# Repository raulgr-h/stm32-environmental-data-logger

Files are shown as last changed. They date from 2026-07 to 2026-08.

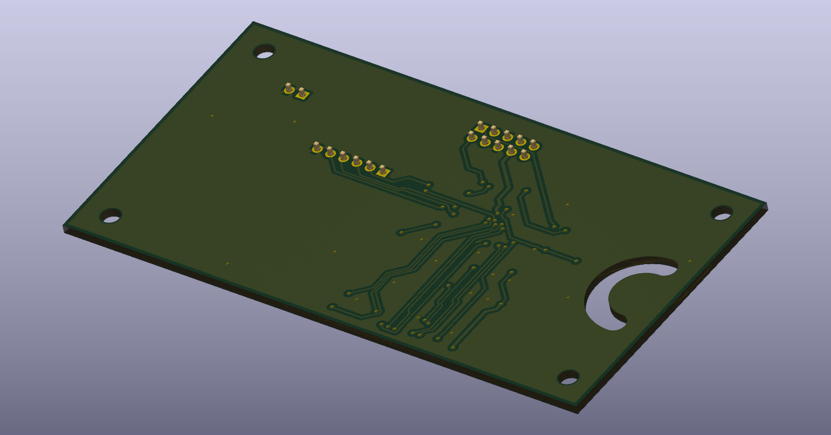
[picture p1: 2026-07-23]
hardware/renders/3dview_bottom.png

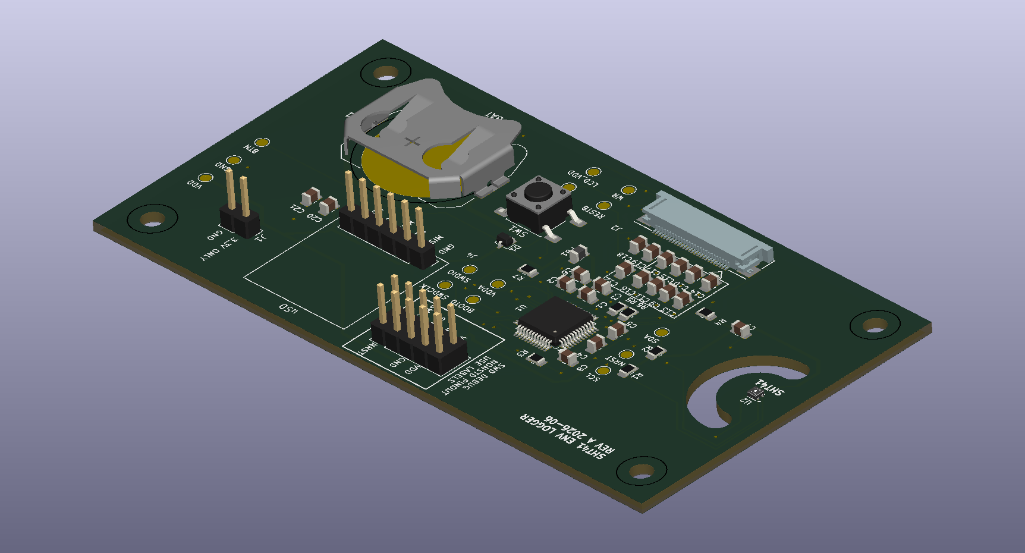
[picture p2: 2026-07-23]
hardware/renders/3dview_opposite.png

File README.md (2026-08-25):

# STM32L431 Environmental Data Logger

A custom embedded environmental data logger built around the STM32L431 microcontroller.

The project began as a hand-assembled Rev A PCB integrating an SHT41 environmental sensor, SPI microSD storage, RTC timestamping, and STM32 firmware. Rev A was brought through board bring-up, firmware integration, protocol debugging, long-duration logging, and electrical characterization.

Development has now progressed to a Rev B redesign informed by measured Rev A behavior, with emphasis on lower-power operation, improved nonvolatile storage, BLE connectivity, and systematic hardware validation.

---

## Project Status

### Rev A — Functional and Characterized

The core Rev A environmental logging path has been successfully brought up and verified.

Verified functionality includes:

- STM32L431 firmware execution and SWD debugging
- SHT41 temperature and relative-humidity measurements over I2C
- SPI-mode microSD initialization and sector access
- FatFs mount, file open, append, write, sync, and close operations
- STM32 RTC initialization and timestamp generation
- RTC-timestamped, PC-readable CSV logging
- Nonblocking push-button-controlled logging
- Multi-hour logging operation
- Zero observed SPI transfer failures during verified long-duration runs
- Logic-analyzer verification of I2C and SPI transactions
- Oscilloscope and Analog Discovery 2 electrical measurements
- Board-level current and supply-transient characterization
- Automated CR2032 pulse-load characterization

Rev A is retained as the verified hardware baseline for continued development.

### Rev B — In Development

Rev B is being developed from Rev A test results and system-level lessons.

Current design changes include:

- Replacement of microSD storage with an ST M95P16 SPI Page EEPROM
- Addition of a 32.768 kHz LSE crystal for RTC and low-power operation
- Addition of a CYBLE-416045-02 BLE module
- STM32-to-BLE UART communication
- Dedicated BLE programming/debug access
- Revised low-power architecture
- Updated user controls and interfaces
- PCB changes informed by measured battery and transient-load behavior

Rev B schematic development is maintained separately from the archived Rev A hardware baseline.

---

## System Architecture

### Rev A

- **Microcontroller:** STM32L431CBT6
- **Environmental Sensor:** Sensirion SHT41
- **Sensor Interface:** I2C
- **Storage:** microSD over SPI
- **Filesystem:** FatFs
- **Timekeeping:** STM32 RTC
- **Firmware:** Embedded C using STM32 HAL
- **PCB Design:** KiCad
- **Development Environment:** STM32CubeIDE
- **Test Equipment:** Digilent Analog Discovery 2, DMM, oscilloscope, and logic analyzer

### Rev B

- **Microcontroller:** STM32L431CBT6
- **Environmental Sensor:** Sensirion SHT41
- **Nonvolatile Storage:** ST M95P16 SPI Page EEPROM
- **Wireless Interface:** Infineon CYBLE-416045-02 BLE module
- **BLE Host Interface:** UART
- **RTC Reference:** External 32.768 kHz LSE crystal
- **PCB Design:** KiCad

---

## Firmware Development

Rev A firmware includes:

- STM32 HAL peripheral configuration
- SHT41 command and measurement handling
- Low-level SPI SD communication
- SD initialization using CMD0, CMD8, CMD55, ACMD41, and CMD58
- Sector-level SD access
- FatFs disk-I/O integration
- RTC initialization and timestamp generation
- Backup-register handling for RTC state
- Timestamped CSV creation and append operations
- Nonblocking push-button debounce and logging-state control
- Reusable sensor-to-storage logging routines
- SPI error instrumentation
- Time-based communication timeout handling

Rev B firmware development will extend the platform with:

- SPI EEPROM storage
- Lower-power operating modes
- BLE coprocessor communication
- Wireless environmental-data transfer

---

## Automated Test and Characterization

A Python-based automated test environment was developed using the Digilent WaveForms SDK and Analog Discovery 2.

The test fixture uses transistor-switched resistive loads and synchronized analog acquisition to characterize battery and PCB supply behavior under controlled transient loads.

Capabilities include:

- Automated selection of multiple load conditions
- Configurable pulse durations
- Repeated transient tests
- Analog acquisition at up to 100 kS/s
- Synchronized battery and shunt-voltage measurement
- Current calculation from calibrated shunt measurements
- Pre-pulse baseline measurement
- Minimum battery-voltage detection
- PCB supply-voltage analysis
- Voltage-droop calculation
- Recovery-voltage analysis
- Pulse-duration validation
- Acquisition-integrity monitoring
- Per-test raw waveform CSV logging
- Reduced summary-metric generation
- Automatic load removal after each test
- Configurable 2.40 V low-voltage safety cutoff

The characterization framework progressed from basic manual load switching and averaged measurements to automated transient waveform capture, focused pulse testing, and repeatability testing.

These measurements are being used to inform Rev B power, storage, and low-power design decisions.

---

## Electrical Characterization

Rev A current and supply behavior were measured during normal environmental logging and controlled load testing.

Verified observations include:

- Approximately **2.1 mA average board current** during 5 s interval logging
- Sampled transient current peaks of approximately **25 mA** at 500 kHz during sensor and microSD activity
- Measurable VDD droop correlated with current transients
- Successful CSV writes despite the observed transient supply behavior
- Repeatable CR2032 transient-load measurements using automated acquisition
- Preservation of raw waveforms for later engineering analysis

The automated test setup enables battery behavior to be compared across different loads, pulse durations, and repeated test runs rather than relying only on static current measurements.

---

## Verification

The system has been verified using:

- STM32CubeIDE debugging
- Runtime firmware instrumentation
- DMM resistance, continuity, and voltage measurements
- Oscilloscope measurements
- Digilent Analog Discovery 2 analog acquisition
- Logic-analyzer protocol captures
- Long-duration CSV logging
- Automated transient-load testing
- Repeatability testing
- Git revision and diff analysis during debugging

Key verified results include:

- `FR_OK` for successful FatFs mount, open, write, sync, and close operations
- `HAL_OK` during verified SHT41 communication
- Successful SPI SD initialization
- Successful CMD17 read transactions
- Verified SHT41 I2C command and response transactions
- RTC-timestamped, PC-readable CSV files
- Button input correlated with subsequent sensor sampling and storage activity
- Multi-hour logging with zero observed SPI transfer failures during verified runs

---

## Debugging Case Studies

### SD Hardware Fault

During Rev A bring-up, the SD card ground connection measured approximately 5 MΩ because of a poor solder joint.

The fault was isolated using resistance and continuity measurements and corrected by reflowing the affected connection.

This restored a valid low-resistance ground connection and allowed SD communication debugging to continue.

### FatFs Write Failure

A later firmware issue caused the first FatFs write operation to appear to hang.

Investigation showed that the SPI peripheral remained at the low initialization clock after SD startup while the disk driver used iteration-count-based ready timeouts.

The corrective actions included:

- Increasing the SPI clock after SD initialization
- Replacing iteration-count polling with `HAL_GetTick()`-based timeouts
- Adding SPI transfer-failure instrumentation

After correction, file open, write, sync, and close operations completed successfully.

### CubeMX Regeneration Regression

A later STM32CubeMX regeneration overwrote the customized `user_diskio.c` implementation, causing FatFs operations to return `FR_NOT_READY`.

The regression was isolated using:

- Runtime return-code instrumentation
- Git revision comparison
- Source diff analysis

Restoring the previously verified disk-I/O implementation recovered normal SD and FatFs operation.

This demonstrated the use of source control not only for version management, but also as a firmware-debugging and regression-analysis tool.

---

## Hardware Revision Strategy

Rev A is retained as a frozen hardware baseline rather than being modified in place.

Rev B development is maintained separately so design changes can be traced back to measured Rev A behavior and validation results.

```text
hardware/kicad/
├── rev-a/          Verified Rev A hardware baseline
├── rev-b/          Rev B hardware development
├── symbols/        Project-specific schematic symbols
├── footprints/     Project-specific PCB footprints
└── 3dmodels/       Component mechanical models
```

The `rev-a-hardware` Git tag preserves the Rev A hardware milestone.

---

## Repository Structure

```text
hardware/
└── kicad/
    ├── rev-a/
    ├── rev-b/
    ├── symbols/
    ├── footprints/
    └── 3dmodels/

firmware/
└── STM32CubeIDE project and embedded firmware

test/
├── scripts/
│   └── ate/
├── raw-data/
├── processed-data/
└── results/

docs/
├── design/
├── bringup/
└── images/

releases/
└── Release and milestone documentation
```

### Automated Test Scripts

The primary automated characterization scripts are maintained under:

```text
test/scripts/ate/
```

They cover:

- Full pulse-load characterization
- Focused pulse testing
- Repeatability testing
- Rev A system-level load testing

Raw acquisition data and processed engineering results are maintained separately to preserve traceability between measurement evidence and reduced summary metrics.

---

## Engineering Scope

This project serves as an end-to-end embedded hardware development platform covering:

- PCB schematic and layout development
- Hardware revision control
- Hand assembly and board bring-up
- STM32 embedded firmware development
- I2C and SPI protocol implementation
- Sensor integration
- Embedded filesystem integration
- RTC and timestamped data acquisition
- Hardware/firmware debugging
- Oscilloscope and logic-analyzer validation
- Automated hardware testing
- Python test automation
- Battery and transient-load characterization
- Root-cause failure analysis
- Design-for-low-power development
- BLE subsystem development
- Git/GitHub engineering workflow

---

## Next Development Steps

Current development is focused on Rev B, including:

- Completing Rev B schematic design review
- PCB layout and design-rule verification
- M95P16 storage-driver development
- BLE subsystem prototyping and UART communication
- Low-power firmware development
- Rev B assembly and bring-up
- Power-consumption comparison between Rev A and Rev B
- Environmental logging validation using the revised architecture

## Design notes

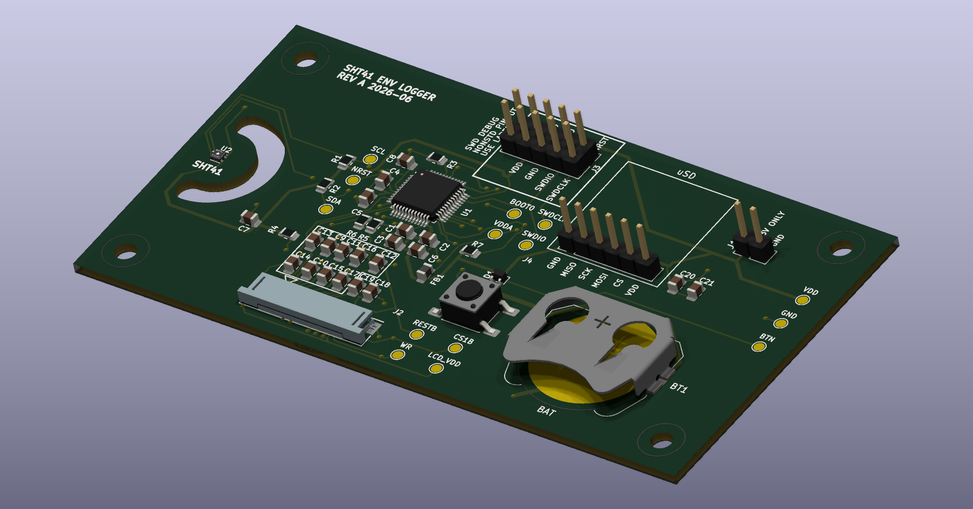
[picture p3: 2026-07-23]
hardware/renders/3dview_top.png

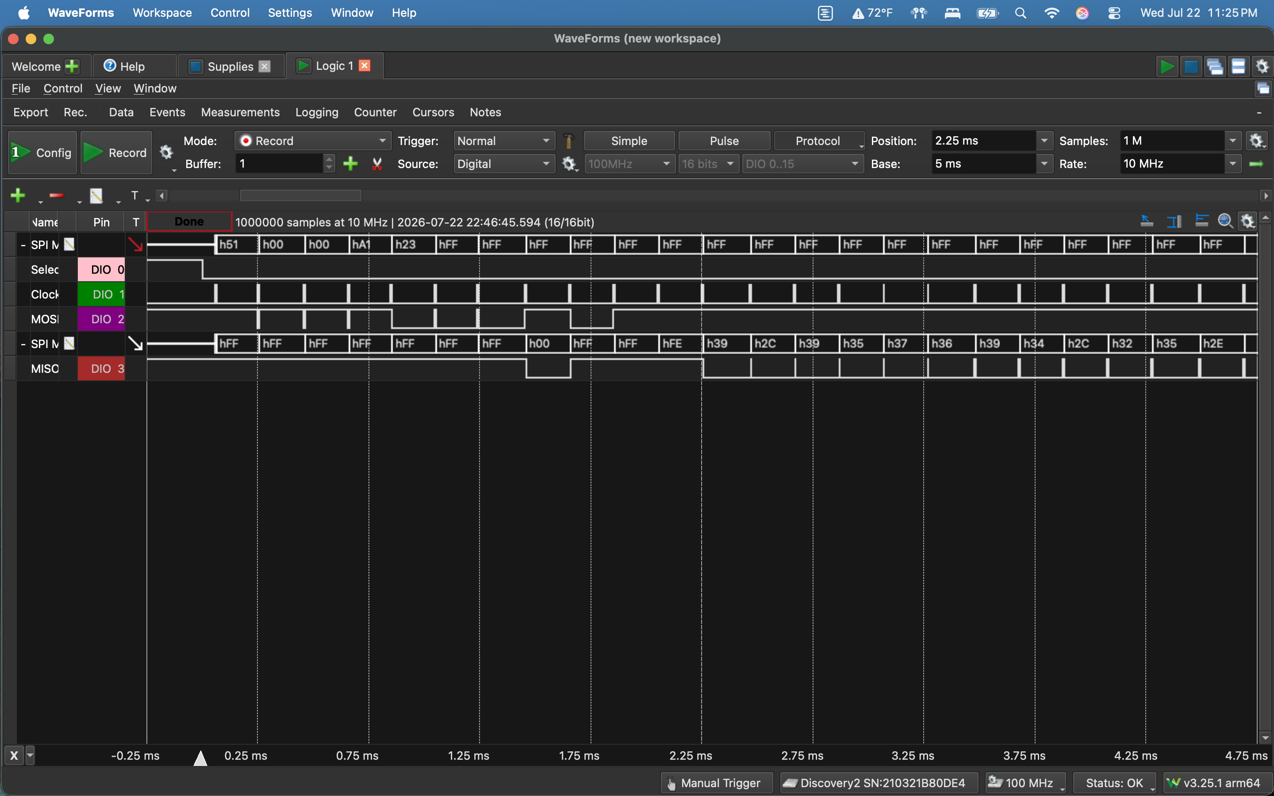
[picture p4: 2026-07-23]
docs/images/Waveforms/SD SPI Transaction - Logic.png

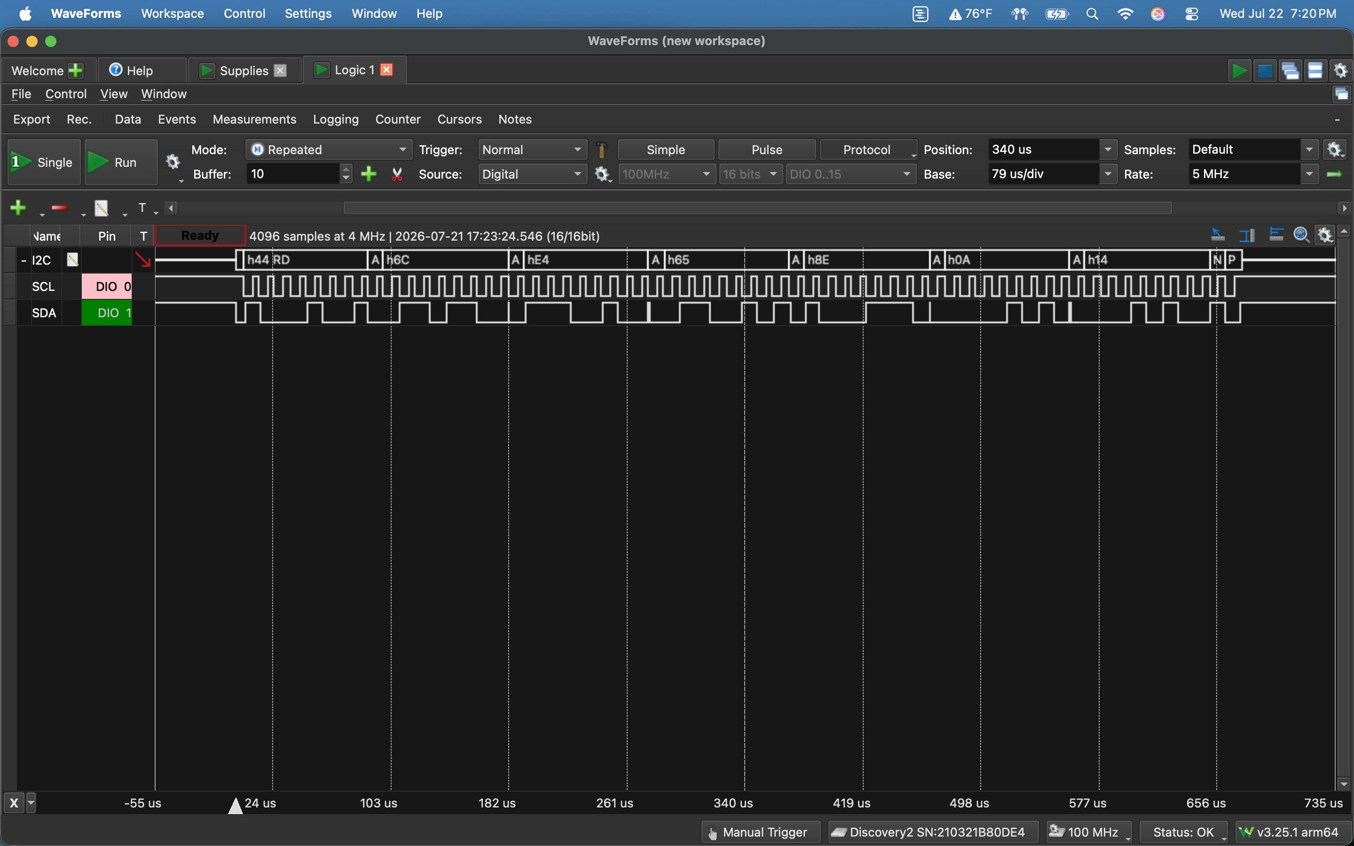
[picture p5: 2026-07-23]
docs/images/Waveforms/I2C transaction for SHT41 - Logic.png

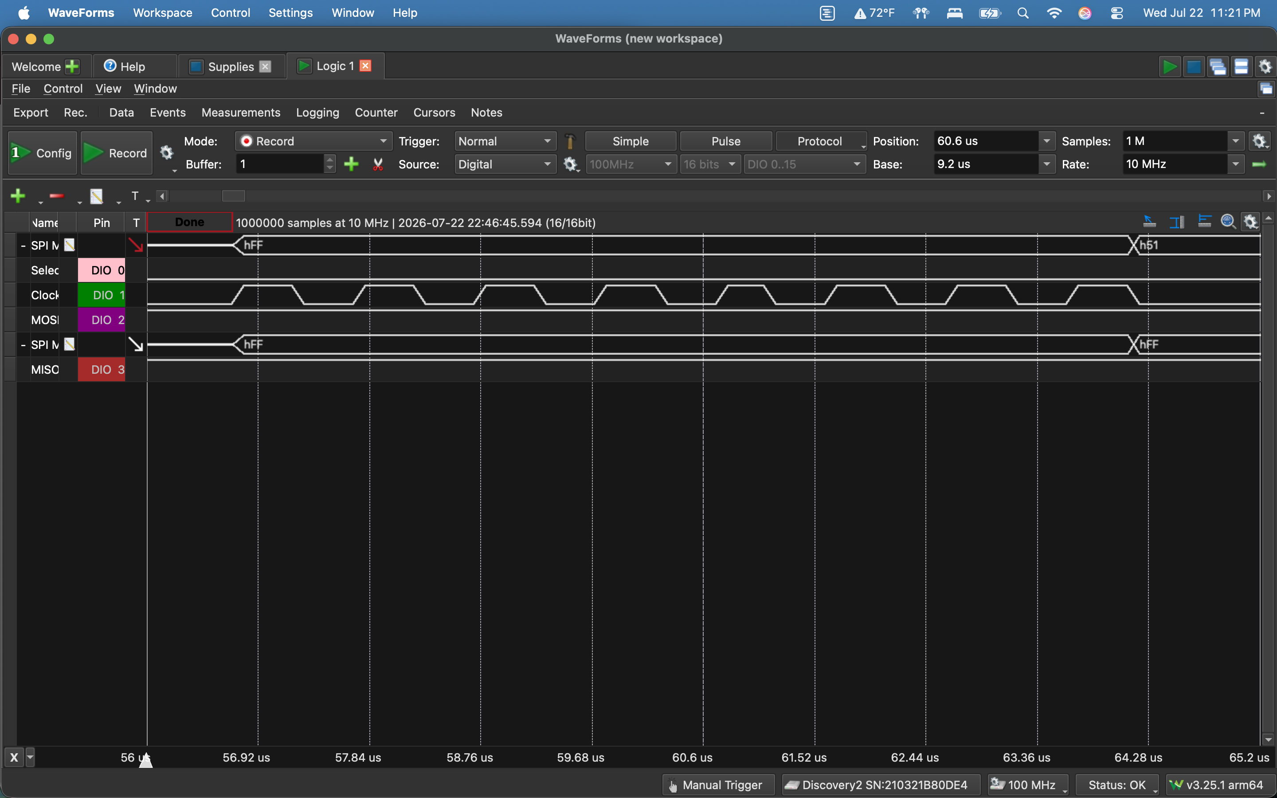
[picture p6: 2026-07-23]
docs/images/Waveforms/SD SPI Transaction (Zoomed) - Logic.png

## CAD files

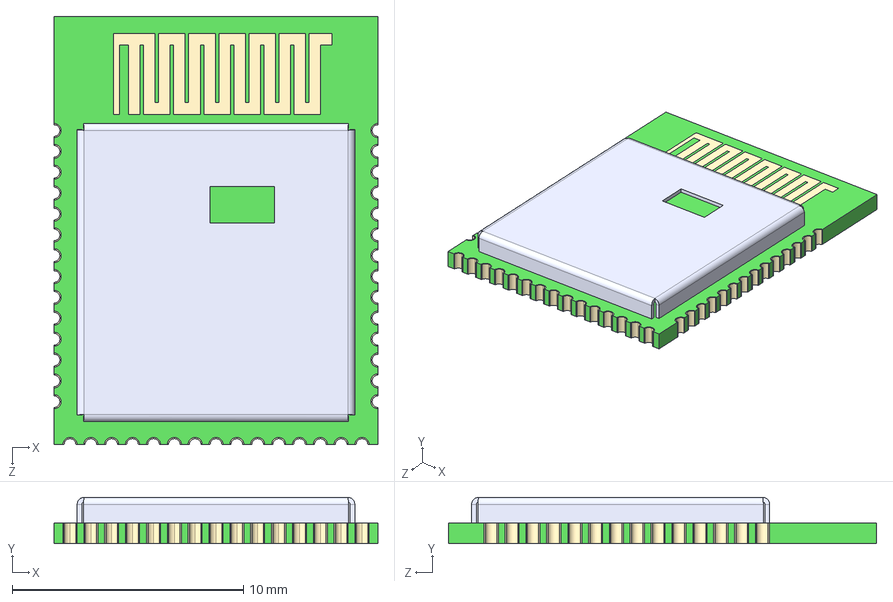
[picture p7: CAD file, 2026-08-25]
hardware/kicad/3dmodels/CYBLE-416045-02.step
14.0 x 2.00 x 18.5 mm

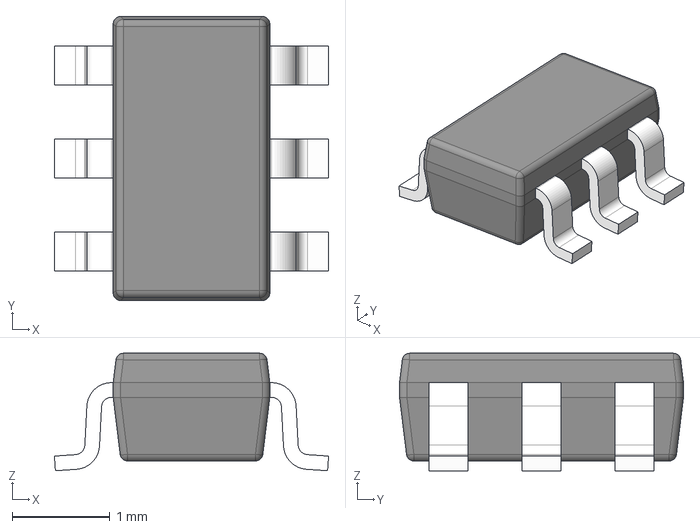
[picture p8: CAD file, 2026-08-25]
hardware/kicad/3dmodels/DBV0006A.stp
2.80 x 2.90 x 1.20 mm
BODY-SOT
LEAD-SOT x 6

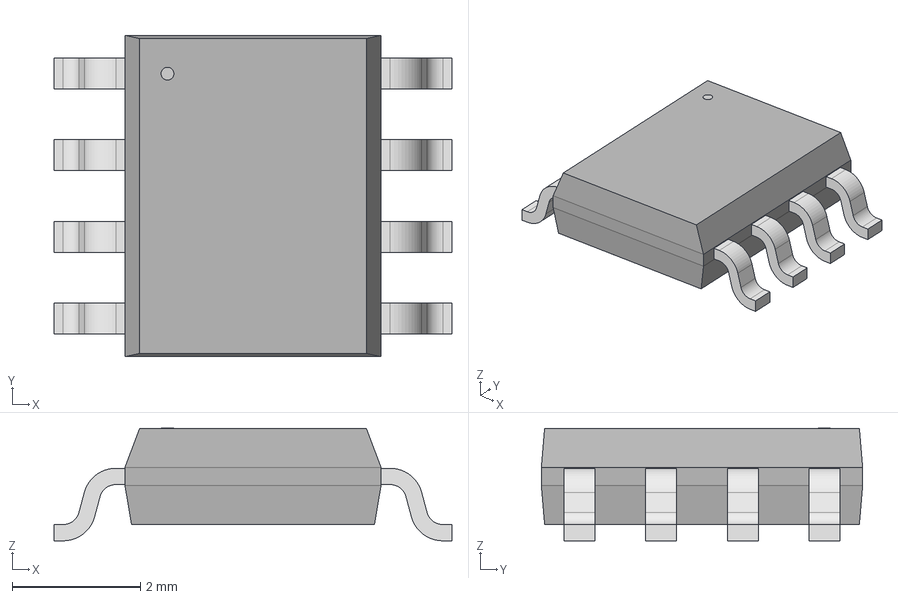
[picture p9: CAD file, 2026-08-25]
hardware/kicad/3dmodels/SO8N_4x5_FTL1p27_STM.step
6.20 x 5.00 x 1.75 mm

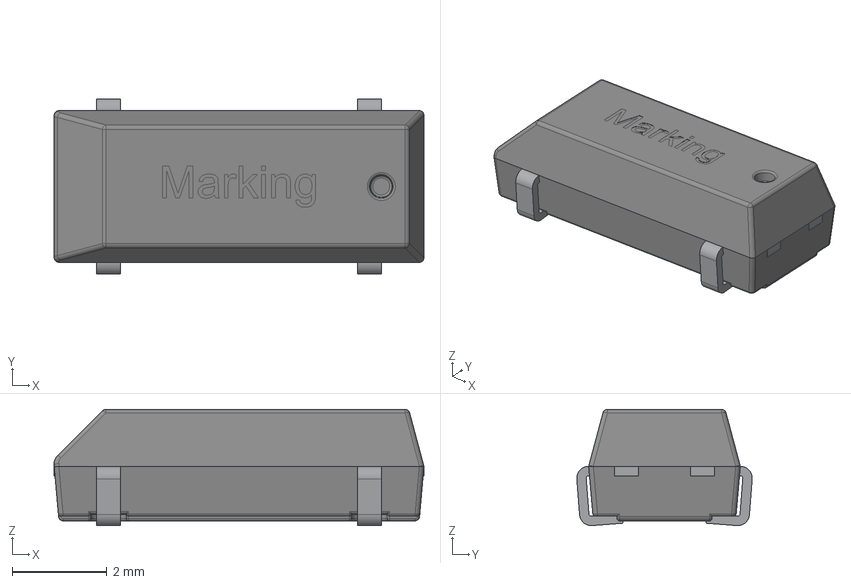
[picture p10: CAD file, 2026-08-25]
hardware/kicad/3dmodels/LFXTAL016178.step
7.80 x 3.70 x 2.45 mm
Base
TopCover
Pin

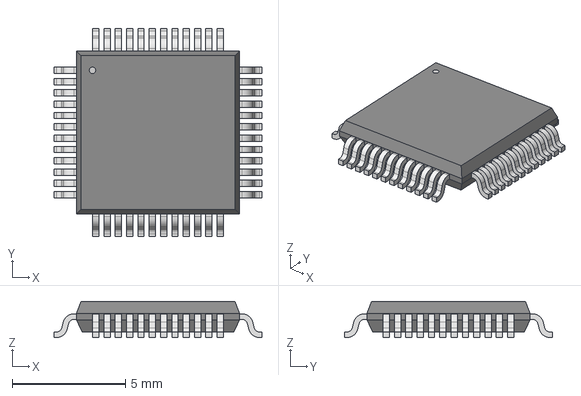
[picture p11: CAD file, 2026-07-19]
hardware/kicad/3dmodels/LQFP-48.step
9.19 x 9.19 x 1.60 mm

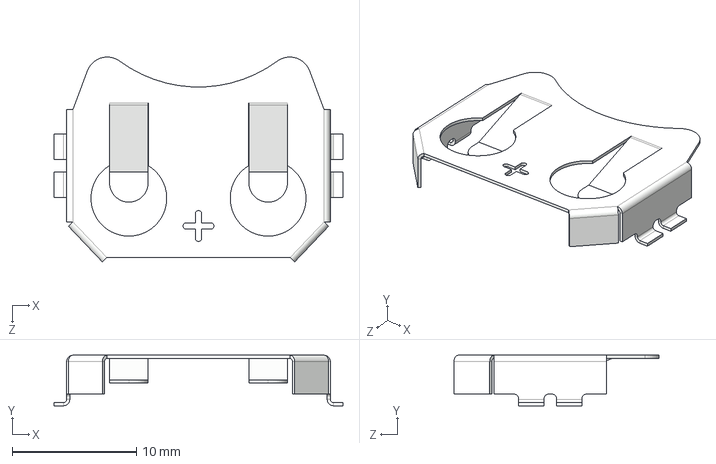
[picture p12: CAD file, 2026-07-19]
hardware/kicad/3dmodels/3034.step
23.2 x 4.06 x 16.5 mm

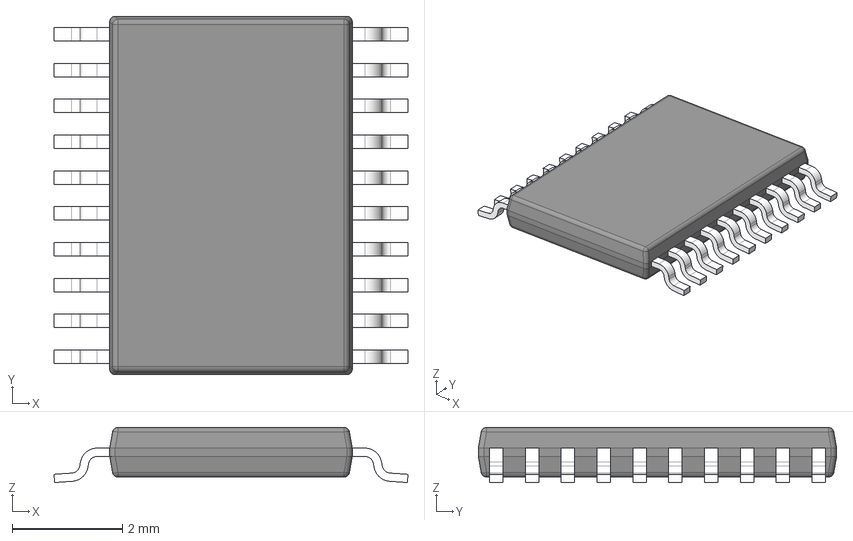
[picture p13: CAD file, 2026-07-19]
hardware/kicad/3dmodels/PWP0020A.stp
6.42 x 6.50 x 1.00 mm
BODY-SO
LEAD-SO x 20
THERMALPAD-SO
PIN1-ID

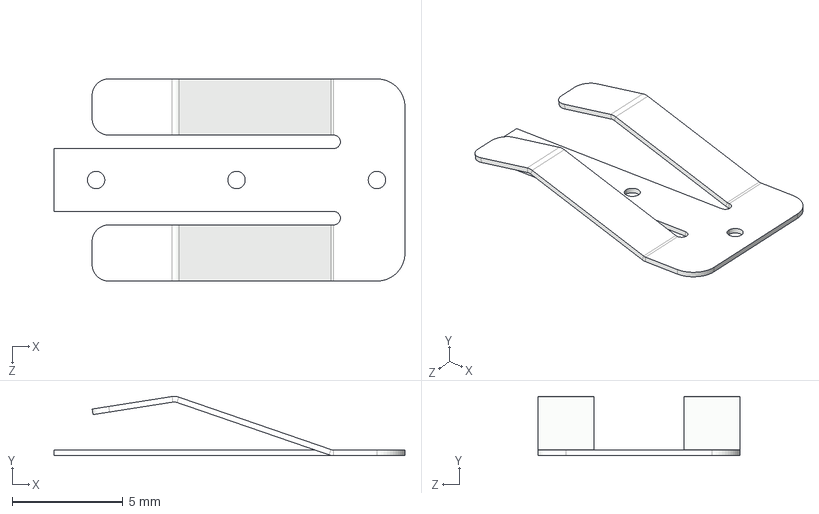
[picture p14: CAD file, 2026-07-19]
hardware/kicad/3dmodels/2993.STEP
15.9 x 2.68 x 9.14 mm

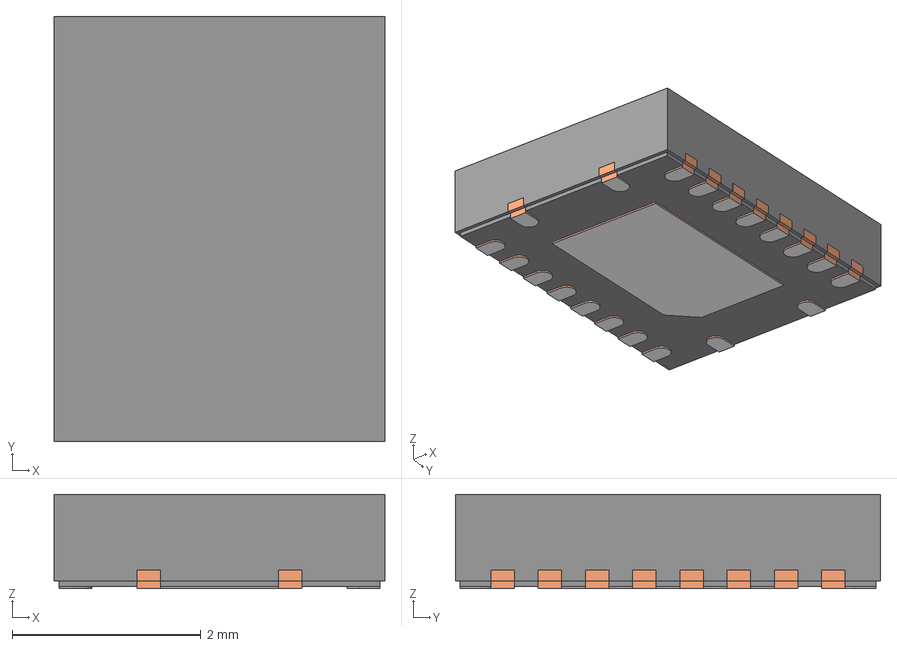
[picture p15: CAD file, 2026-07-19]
hardware/kicad/3dmodels/RGY0020B.stp
3.50 x 4.50 x 1.00 mm
BODY-QFN_AF0
FRAME-RGY0020B_AF0
PIN1-ID

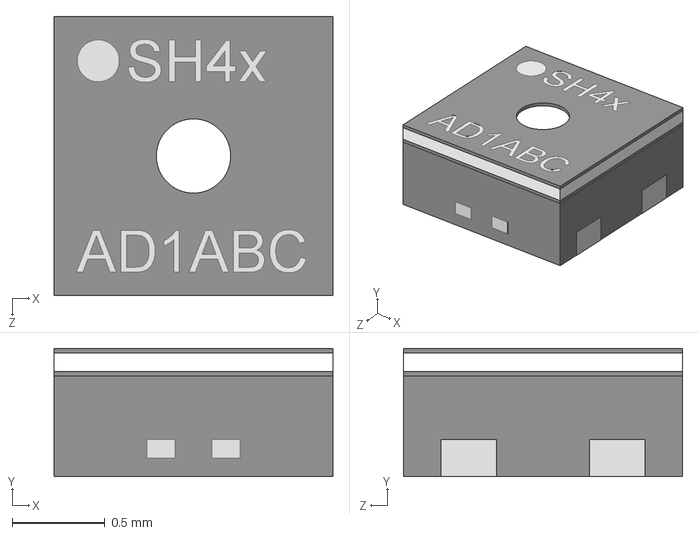
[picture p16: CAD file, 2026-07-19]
hardware/kicad/3dmodels/SHT41-AD1B-R3.step
1.50 x 0.691 x 1.50 mm

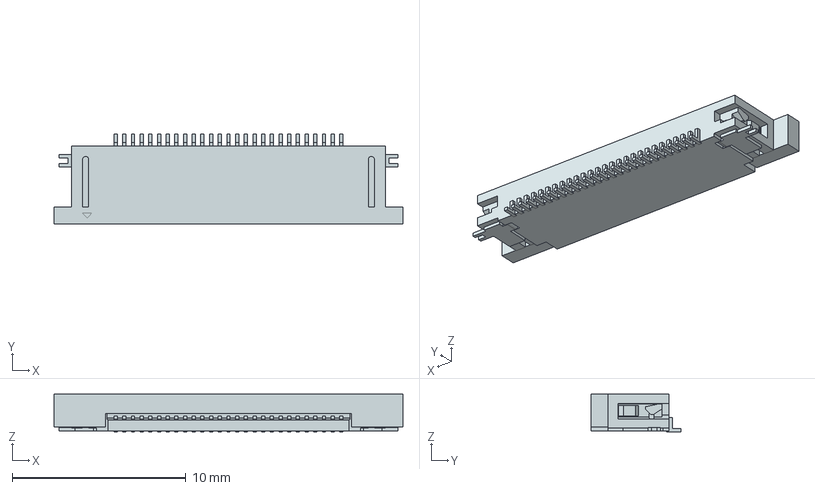
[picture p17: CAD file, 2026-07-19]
hardware/kicad/3dmodels/524372771.stp
20.1 x 5.20 x 2.16 mm

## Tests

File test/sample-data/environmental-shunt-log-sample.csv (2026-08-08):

sample | timestamp | temp_C | rh_pct
0 | 8/2/26 0:00 | 26.6 | 70.19
1 | 8/2/26 0:00 | 26.64 | 70.23
2 | 8/2/26 0:00 | 26.62 | 70.2
3 | 8/2/26 0:00 | 26.6 | 70.18
4 | 8/2/26 0:00 | 26.61 | 70.19
5 | 8/2/26 0:00 | 26.59 | 70.21

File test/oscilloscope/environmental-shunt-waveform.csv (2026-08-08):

#Digilent WaveForms Oscilloscope Measurements
#Device Name: Discovery2
#Serial Number: SN:210321B80DE4
#Date Time: 2026-08-06 22:46:36.892
#Sample rate: 500000Hz
#Samples: 10000000
#Trigger: Source: Channel 1 Type: Edge Condition: Rising Level: 0 V Hyst.: Auto HoldOff: 0 s
#Channel 1: Range: 5 mV/div Offset: -20 mV Sample Mode: Average
#Channel 2: Range: 100 mV/div Offset: -3.04 V Sample Mode: Average
#Power Supplies: OFF
#Positive Supply: Rdy
#Voltage: 3.3 V
#Negative Supply: OFF
#Voltage: -1 V
,Extent,Name
C1,High, 24.836 mV
C1,Peak2Peak, 34.941 mV
C1,Average, 2.1034 mV
C2,Minimum, 2.8723 V
C2,Average, 3.2785 V
C2,Peak2Peak, 422.91 mV

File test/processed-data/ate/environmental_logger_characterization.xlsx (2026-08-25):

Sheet: Test_Summary
Final_Valid | TRUE
Row Labels | Average of avg_added_current_mA | Average of battery_droop_mV | Average of vbat_min_V | Average of vpcb_min_V | Count of repeat | Min of vbat_min_V | StdDev of vbat_min_V
Aged ~2.90V | 2.702525621 | 416.6478948 | 2.491242599 | 2.489578461 | 9 | 2.480257638 | 0.01051729946
996ohm_10ms | 2.712285326 | 408.0892513 | 2.500030568 | 2.498426737 | 5 | 2.498565907 | 0.002005570314
996ohm_100ms | 2.69032599 | 427.3461992 | 2.480257638 | 2.478518116 | 4 | 2.480257638 | 0
Fresh ~3.05V | 9.800991461 | 119.8915886 | 2.926063973 | 2.920479864 | 24 | 2.868392928 | 0.03254101151
220ohm_10ms | 14.9062645 | 174.0720863 | 2.87132225 | 2.862933855 | 5 | 2.868392928 | 0.001637541304
329ohm_100ms | 10.07758955 | 124.7504169 | 2.92038841 | 2.914781686 | 5 | 2.912332772 | 0.006016710944
329ohm_10ms | 9.607554343 | 116.8816696 | 2.929908709 | 2.924437677 | 5 | 2.926979386 | 0.001637541304
550ohm_100ms | 7.022302052 | 90.14361539 | 2.956272616 | 2.952226342 | 5 | 2.956272616 | 4.214684851e-08
550ohm_10ms | 6.788810712 | 87.03979634 | 2.959018856 | 2.954904736 | 4 | 2.952610962 | 0.004607479832
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

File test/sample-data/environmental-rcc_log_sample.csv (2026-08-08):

sample | timestamp | temp_C | rh_pct
0 | 8/2/26 0:00 | 25.89 | 70.89
1 | 8/2/26 0:00 | 25.91 | 70.89
2 | 8/2/26 0:00 | 25.91 | 70.9
3 | 8/2/26 0:00 | 25.95 | 70.85
4 | 8/2/26 0:00 | 25.95 | 70.89
5 | 8/2/26 0:00 | 25.99 | 70.89
6 | 8/2/26 0:00 | 26.01 | 70.89
0 | 8/2/26 0:00 | 25.73 | 70.76
0 | 8/2/26 0:00 | 25.71 | 70.78
1 | 8/2/26 0:00 | 25.69 | 70.75
2 | 8/2/26 0:00 | 25.71 | 70.75
0 | 8/2/26 0:06 | 25.74 | 70.74
1 | 8/2/26 0:06 | 25.7 | 70.72
2 | 8/2/26 0:06 | 25.71 | 70.71
3 | 8/2/26 0:06 | 25.7 | 70.71
4 | 8/2/26 0:06 | 25.63 | 70.7
5 | 8/2/26 0:06 | 25.61 | 70.69
6 | 8/2/26 0:06 | 25.61 | 70.71
7 | 8/2/26 0:06 | 25.61 | 70.69
8 | 8/2/26 0:06 | 25.65 | 70.69
9 | 8/2/26 0:06 | 25.67 | 70.72
0 | 8/2/26 0:08 | 26 | 70.78
1 | 8/2/26 0:08 | 26.04 | 70.77
2 | 8/2/26 0:08 | 26.07 | 70.77
3 | 8/2/26 0:08 | 26.08 | 70.76
0 | 8/2/26 0:17 | 25.77 | 70.66
1 | 8/2/26 0:17 | 25.76 | 70.66
2 | 8/2/26 0:17 | 25.77 | 70.68
3 | 8/2/26 0:17 | 25.77 | 70.68
4 | 8/2/26 0:17 | 25.75 | 70.67
5 | 8/2/26 0:17 | 25.77 | 70.66
6 | 8/2/26 0:17 | 25.7 | 70.66
7 | 8/2/26 0:17 | 25.72 | 70.64
8 | 8/2/26 0:17 | 25.75 | 70.64
9 | 8/2/26 0:17 | 25.72 | 70.65
10 | 8/2/26 0:18 | 25.68 | 70.64
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

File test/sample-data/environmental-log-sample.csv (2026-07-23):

{\rtf1\ansi\ansicpg1252\cocoartf2870
\cocoatextscaling0\cocoaplatform0{\fonttbl\f0\fswiss\fcharset0 Helvetica;}
{\colortbl;\red255\green255\blue255;\red191\green191\blue191;}
{\*\expandedcolortbl;;\csgray\c79525;}
\margl1440\margr1440\vieww11520\viewh8400\viewkind0
\deftab720
\itap1\trowd \taflags1 \trgaph108\trleft-108 \trbrdrt\brdrnil \trbrdrl\brdrnil \trbrdrr\brdrnil
\clvertalc \clshdrawnil \clbrdrt\brdrs\brdrw20\brdrcf2 \clbrdrl\brdrs\brdrw20\brdrcf2 \clbrdrb\brdrs\brdrw20\brdrcf2 \clbrdrr\brdrs\brdrw20\brdrcf2 \clpadl100 \clpadr100 \gaph\cellx2160
\clvertalc \clshdrawnil \clbrdrt\brdrs\brdrw20\brdrcf2 \clbrdrl\brdrs\brdrw20\brdrcf2 \clbrdrb\brdrs\brdrw20\brdrcf2 \clbrdrr\brdrs\brdrw20\brdrcf2 \clpadl100 \clpadr100 \gaph\cellx4320
\clvertalc \clshdrawnil \clbrdrt\brdrs\brdrw20\brdrcf2 \clbrdrl\brdrs\brdrw20\brdrcf2 \clbrdrb\brdrs\brdrw20\brdrcf2 \clbrdrr\brdrs\brdrw20\brdrcf2 \clpadl100 \clpadr100 \gaph\cellx6480
\clvertalc \clshdrawnil \clbrdrt\brdrs\brdrw20\brdrcf2 \clbrdrl\brdrs\brdrw20\brdrcf2 \clbrdrb\brdrs\brdrw20\brdrcf2 \clbrdrr\brdrs\brdrw20\brdrcf2 \clpadl100 \clpadr100 \gaph\cellx8640
\pard\intbl\itap1\pardeftab720\partightenfactor0
\f0\fs24 \cf0 sample\cell
\pard\intbl\itap1\pardeftab720\partightenfactor0
\cf0 time_ms\cell
\pard\intbl\itap1\pardeftab720\partightenfactor0
\cf0 temp_C\cell
\pard\intbl\itap1\pardeftab720\partightenfactor0
\cf0 rh_pct\cell \row
\itap1\trowd \taflags1 \trgaph108\trleft-108 \trbrdrl\brdrnil \trbrdrr\brdrnil
\clvertalc \clshdrawnil \clbrdrt\brdrs\brdrw20\brdrcf2 \clbrdrl\brdrs\brdrw20\brdrcf2 \clbrdrb\brdrs\brdrw20\brdrcf2 \clbrdrr\brdrs\brdrw20\brdrcf2 \clpadl100 \clpadr100 \gaph\cellx2160
\clvertalc \clshdrawnil \clbrdrt\brdrs\brdrw20\brdrcf2 \clbrdrl\brdrs\brdrw20\brdrcf2 \clbrdrb\brdrs\brdrw20\brdrcf2 \clbrdrr\brdrs\brdrw20\brdrcf2 \clpadl100 \clpadr100 \gaph\cellx4320
\clvertalc \clshdrawnil \clbrdrt\brdrs\brdrw20\brdrcf2 \clbrdrl\brdrs\brdrw20\brdrcf2 \clbrdrb\brdrs\brdrw20\brdrcf2 \clbrdrr\brdrs\brdrw20\brdrcf2 \clpadl100 \clpadr100 \gaph\cellx6480
\clvertalc \clshdrawnil \clbrdrt\brdrs\brdrw20\brdrcf2 \clbrdrl\brdrs\brdrw20\brdrcf2 \clbrdrb\brdrs\brdrw20\brdrcf2 \clbrdrr\brdrs\brdrw20\brdrcf2 \clpadl100 \clpadr100 \gaph\cellx8640
\pard\intbl\itap1\pardeftab720\qr\partightenfactor0
\cf0 0\cell
\pard\intbl\itap1\pardeftab720\qr\partightenfactor0
\cf0 414\cell
\pard\intbl\itap1\pardeftab720\qr\partightenfactor0
\cf0 25.28\cell
\pard\intbl\itap1\pardeftab720\qr\partightenfactor0
\cf0 67.62\cell \row
\itap1\trowd \taflags1 \trgaph108\trleft-108 \trbrdrl\brdrnil \trbrdrr\brdrnil
\clvertalc \clshdrawnil \clbrdrt\brdrs\brdrw20\brdrcf2 \clbrdrl\brdrs\brdrw20\brdrcf2 \clbrdrb\brdrs\brdrw20\brdrcf2 \clbrdrr\brdrs\brdrw20\brdrcf2 \clpadl100 \clpadr100 \gaph\cellx2160
\clvertalc \clshdrawnil \clbrdrt\brdrs\brdrw20\brdrcf2 \clbrdrl\brdrs\brdrw20\brdrcf2 \clbrdrb\brdrs\brdrw20\brdrcf2 \clbrdrr\brdrs\brdrw20\brdrcf2 \clpadl100 \clpadr100 \gaph\cellx4320
\clvertalc \clshdrawnil \clbrdrt\brdrs\brdrw20\brdrcf2 \clbrdrl\brdrs\brdrw20\brdrcf2 \clbrdrb\brdrs\brdrw20\brdrcf2 \clbrdrr\brdrs\brdrw20\brdrcf2 \clpadl100 \clpadr100 \gaph\cellx6480
\clvertalc \clshdrawnil \clbrdrt\brdrs\brdrw20\brdrcf2 \clbrdrl\brdrs\brdrw20\brdrcf2 \clbrdrb\brdrs\brdrw20\brdrcf2 \clbrdrr\brdrs\brdrw20\brdrcf2 \clpadl100 \clpadr100 \gaph\cellx8640
\pard\intbl\itap1\pardeftab720\qr\partightenfactor0
\cf0 1\cell
\pard\intbl\itap1\pardeftab720\qr\partightenfactor0
\cf0 6621\cell
\pard\intbl\itap1\pardeftab720\qr\partightenfactor0
\cf0 25.29\cell
\pard\intbl\itap1\pardeftab720\qr\partightenfactor0
\cf0 67.6\cell \row
\itap1\trowd \taflags1 \trgaph108\trleft-108 \trbrdrl\brdrnil \trbrdrr\brdrnil
\clvertalc \clshdrawnil \clbrdrt\brdrs\brdrw20\brdrcf2 \clbrdrl\brdrs\brdrw20\brdrcf2 \clbrdrb\brdrs\brdrw20\brdrcf2 \clbrdrr\brdrs\brdrw20\brdrcf2 \clpadl100 \clpadr100 \gaph\cellx2160
\clvertalc \clshdrawnil \clbrdrt\brdrs\brdrw20\brdrcf2 \clbrdrl\brdrs\brdrw20\brdrcf2 \clbrdrb\brdrs\brdrw20\brdrcf2 \clbrdrr\brdrs\brdrw20\brdrcf2 \clpadl100 \clpadr100 \gaph\cellx4320
\clvertalc \clshdrawnil \clbrdrt\brdrs\brdrw20\brdrcf2 \clbrdrl\brdrs\brdrw20\brdrcf2 \clbrdrb\brdrs\brdrw20\brdrcf2 \clbrdrr\brdrs\brdrw20\brdrcf2 \clpadl100 \clpadr100 \gaph\cellx6480
\clvertalc \clshdrawnil \clbrdrt\brdrs\brdrw20\brdrcf2 \clbrdrl\brdrs\brdrw20\brdrcf2 \clbrdrb\brdrs\brdrw20\brdrcf2 \clbrdrr\brdrs\brdrw20\brdrcf2 \clpadl100 \clpadr100 \gaph\cellx8640
\pard\intbl\itap1\pardeftab720\qr\partightenfactor0
\cf0 2\cell
\pard\intbl\itap1\pardeftab720\qr\partightenfactor0
\cf0 12073\cell
\pard\intbl\itap1\pardeftab720\qr\partightenfactor0
\cf0 25.27\cell
\pard\intbl\itap1\pardeftab720\qr\partightenfactor0
\cf0 67.64\cell \row
\itap1\trowd \taflags1 \trgaph108\trleft-108 \trbrdrl\brdrnil \trbrdrr\brdrnil
\clvertalc \clshdrawnil \clbrdrt\brdrs\brdrw20\brdrcf2 \clbrdrl\brdrs\brdrw20\brdrcf2 \clbrdrb\brdrs\brdrw20\brdrcf2 \clbrdrr\brdrs\brdrw20\brdrcf2 \clpadl100 \clpadr100 \gaph\cellx2160
\clvertalc \clshdrawnil \clbrdrt\brdrs\brdrw20\brdrcf2 \clbrdrl\brdrs\brdrw20\brdrcf2 \clbrdrb\brdrs\brdrw20\brdrcf2 \clbrdrr\brdrs\brdrw20\brdrcf2 \clpadl100 \clpadr100 \gaph\cellx4320
\clvertalc \clshdrawnil \clbrdrt\brdrs\brdrw20\brdrcf2 \clbrdrl\brdrs\brdrw20\brdrcf2 \clbrdrb\brdrs\brdrw20\brdrcf2 \clbrdrr\brdrs\brdrw20\brdrcf2 \clpadl100 \clpadr100 \gaph\cellx6480
\clvertalc \clshdrawnil \clbrdrt\brdrs\brdrw20\brdrcf2 \clbrdrl\brdrs\brdrw20\brdrcf2 \clbrdrb\brdrs\brdrw20\brdrcf2 \clbrdrr\brdrs\brdrw20\brdrcf2 \clpadl100 \clpadr100 \gaph\cellx8640
\pard\intbl\itap1\pardeftab720\qr\partightenfactor0
\cf0 3\cell
\pard\intbl\itap1\pardeftab720\qr\partightenfactor0
\cf0 17415\cell
\pard\intbl\itap1\pardeftab720\qr\partightenfactor0
\cf0 25.27\cell
\pard\intbl\itap1\pardeftab720\qr\partightenfactor0
\cf0 67.64\cell \row
\itap1\trowd \taflags1 \trgaph108\trleft-108 \trbrdrl\brdrnil \trbrdrr\brdrnil
\clvertalc \clshdrawnil \clbrdrt\brdrs\brdrw20\brdrcf2 \clbrdrl\brdrs\brdrw20\brdrcf2 \clbrdrb\brdrs\brdrw20\brdrcf2 \clbrdrr\brdrs\brdrw20\brdrcf2 \clpadl100 \clpadr100 \gaph\cellx2160
\clvertalc \clshdrawnil \clbrdrt\brdrs\brdrw20\brdrcf2 \clbrdrl\brdrs\brdrw20\brdrcf2 \clbrdrb\brdrs\brdrw20\brdrcf2 \clbrdrr\brdrs\brdrw20\brdrcf2 \clpadl100 \clpadr100 \gaph\cellx4320
\clvertalc \clshdrawnil \clbrdrt\brdrs\brdrw20\brdrcf2 \clbrdrl\brdrs\brdrw20\brdrcf2 \clbrdrb\brdrs\brdrw20\brdrcf2 \clbrdrr\brdrs\brdrw20\brdrcf2 \clpadl100 \clpadr100 \gaph\cellx6480
\clvertalc \clshdrawnil \clbrdrt\brdrs\brdrw20\brdrcf2 \clbrdrl\brdrs\brdrw20\brdrcf2 \clbrdrb\brdrs\brdrw20\brdrcf2 \clbrdrr\brdrs\brdrw20\brdrcf2 \clpadl100 \clpadr100 \gaph\cellx8640
\pard\intbl\itap1\pardeftab720\qr\partightenfactor0
\cf0 4\cell
\pard\intbl\itap1\pardeftab720\qr\partightenfactor0
\cf0 22757\cell
\pard\intbl\itap1\pardeftab720\qr\partightenfactor0
\cf0 25.21\cell
\pard\intbl\itap1\pardeftab720\qr\partightenfactor0
\cf0 67.62\cell \row
\itap1\trowd \taflags1 \trgaph108\trleft-108 \trbrdrl\brdrnil \trbrdrr\brdrnil
\clvertalc \clshdrawnil \clbrdrt\brdrs\brdrw20\brdrcf2 \clbrdrl\brdrs\brdrw20\brdrcf2 \clbrdrb\brdrs\brdrw20\brdrcf2 \clbrdrr\brdrs\brdrw20\brdrcf2 \clpadl100 \clpadr100 \gaph\cellx2160
\clvertalc \clshdrawnil \clbrdrt\brdrs\brdrw20\brdrcf2 \clbrdrl\brdrs\brdrw20\brdrcf2 \clbrdrb\brdrs\brdrw20\brdrcf2 \clbrdrr\brdrs\brdrw20\brdrcf2 \clpadl100 \clpadr100 \gaph\cellx4320
\clvertalc \clshdrawnil \clbrdrt\brdrs\brdrw20\brdrcf2 \clbrdrl\brdrs\brdrw20\brdrcf2 \clbrdrb\brdrs\brdrw20\brdrcf2 \clbrdrr\brdrs\brdrw20\brdrcf2 \clpadl100 \clpadr100 \gaph\cellx6480
\clvertalc \clshdrawnil \clbrdrt\brdrs\brdrw20\brdrcf2 \clbrdrl\brdrs\brdrw20\brdrcf2 \clbrdrb\brdrs\brdrw20\brdrcf2 \clbrdrr\brdrs\brdrw20\brdrcf2 \clpadl100 \clpadr100 \gaph\cellx8640
\pard\intbl\itap1\pardeftab720\qr\partightenfactor0
\cf0 5\cell
\pard\intbl\itap1\pardeftab720\qr\partightenfactor0
\cf0 28099\cell
\pard\intbl\itap1\pardeftab720\qr\partightenfactor0
\cf0 25.18\cell
\pard\intbl\itap1\pardeftab720\qr\partightenfactor0
\cf0 67.58\cell \row
\itap1\trowd \taflags1 \trgaph108\trleft-108 \trbrdrl\brdrnil \trbrdrr\brdrnil
\clvertalc \clshdrawnil \clbrdrt\brdrs\brdrw20\brdrcf2 \clbrdrl\brdrs\brdrw20\brdrcf2 \clbrdrb\brdrs\brdrw20\brdrcf2 \clbrdrr\brdrs\brdrw20\brdrcf2 \clpadl100 \clpadr100 \gaph\cellx2160
\clvertalc \clshdrawnil \clbrdrt\brdrs\brdrw20\brdrcf2 \clbrdrl\brdrs\brdrw20\brdrcf2 \clbrdrb\brdrs\brdrw20\brdrcf2 \clbrdrr\brdrs\brdrw20\brdrcf2 \clpadl100 \clpadr100 \gaph\cellx4320
\clvertalc \clshdrawnil \clbrdrt\brdrs\brdrw20\brdrcf2 \clbrdrl\brdrs\brdrw20\brdrcf2 \clbrdrb\brdrs\brdrw20\brdrcf2 \clbrdrr\brdrs\brdrw20\brdrcf2 \clpadl100 \clpadr100 \gaph\cellx6480
\clvertalc \clshdrawnil \clbrdrt\brdrs\brdrw20\brdrcf2 \clbrdrl\brdrs\brdrw20\brdrcf2 \clbrdrb\brdrs\brdrw20\brdrcf2 \clbrdrr\brdrs\brdrw20\brdrcf2 \clpadl100 \clpadr100 \gaph\cellx8640
\pard\intbl\itap1\pardeftab720\qr\partightenfactor0
\cf0 6\cell
\pard\intbl\itap1\pardeftab720\qr\partightenfactor0
\cf0 33441\cell
\pard\intbl\itap1\pardeftab720\qr\partightenfactor0
\cf0 25.17\cell
\pard\intbl\itap1\pardeftab720\qr\partightenfactor0
\cf0 67.62\cell \row
\itap1\trowd \taflags1 \trgaph108\trleft-108 \trbrdrl\brdrnil \trbrdrr\brdrnil
\clvertalc \clshdrawnil \clbrdrt\brdrs\brdrw20\brdrcf2 \clbrdrl\brdrs\brdrw20\brdrcf2 \clbrdrb\brdrs\brdrw20\brdrcf2 \clbrdrr\brdrs\brdrw20\brdrcf2 \clpadl100 \clpadr100 \gaph\cellx2160
\clvertalc \clshdrawnil \clbrdrt\brdrs\brdrw20\brdrcf2 \clbrdrl\brdrs\brdrw20\brdrcf2 \clbrdrb\brdrs\brdrw20\brdrcf2 \clbrdrr\brdrs\brdrw20\brdrcf2 \clpadl100 \clpadr100 \gaph\cellx4320
\clvertalc \clshdrawnil \clbrdrt\brdrs\brdrw20\brdrcf2 \clbrdrl\brdrs\brdrw20\brdrcf2 \clbrdrb\brdrs\brdrw20\brdrcf2 \clbrdrr\brdrs\brdrw20\brdrcf2 \clpadl100 \clpadr100 \gaph\cellx6480
\clvertalc \clshdrawnil \clbrdrt\brdrs\brdrw20\brdrcf2 \clbrdrl\brdrs\brdrw20\brdrcf2 \clbrdrb\brdrs\brdrw20\brdrcf2 \clbrdrr\brdrs\brdrw20\brdrcf2 \clpadl100 \clpadr100 \gaph\cellx8640
\pard\intbl\itap1\pardeftab720\qr\partightenfactor0
\cf0 7\cell
\pard\intbl\itap1\pardeftab720\qr\partightenfactor0
\cf0 38783\cell
\pard\intbl\itap1\pardeftab720\qr\partightenfactor0
\cf0 25.18\cell
\pard\intbl\itap1\pardeftab720\qr\partightenfactor0
\cf0 67.59\cell \row
\itap1\trowd \taflags1 \trgaph108\trleft-108 \trbrdrl\brdrnil \trbrdrr\brdrnil
\clvertalc \clshdrawnil \clbrdrt\brdrs\brdrw20\brdrcf2 \clbrdrl\brdrs\brdrw20\brdrcf2 \clbrdrb\brdrs\brdrw20\brdrcf2 \clbrdrr\brdrs\brdrw20\brdrcf2 \clpadl100 \clpadr100 \gaph\cellx2160
\clvertalc \clshdrawnil \clbrdrt\brdrs\brdrw20\brdrcf2 \clbrdrl\brdrs\brdrw20\brdrcf2 \clbrdrb\brdrs\brdrw20\brdrcf2 \clbrdrr\brdrs\brdrw20\brdrcf2 \clpadl100 \clpadr100 \gaph\cellx4320
\clvertalc \clshdrawnil \clbrdrt\brdrs\brdrw20\brdrcf2 \clbrdrl\brdrs\brdrw20\brdrcf2 \clbrdrb\brdrs\brdrw20\brdrcf2 \clbrdrr\brdrs\brdrw20\brdrcf2 \clpadl100 \clpadr100 \gaph\cellx6480
\clvertalc \clshdrawnil \clbrdrt\brdrs\brdrw20\brdrcf2 \clbrdrl\brdrs\brdrw20\brdrcf2 \clbrdrb\brdrs\brdrw20\brdrcf2 \clbrdrr\brdrs\brdrw20\brdrcf2 \clpadl100 \clpadr100 \gaph\cellx8640
\pard\intbl\itap1\pardeftab720\qr\partightenfactor0
\cf0 8\cell
\pard\intbl\itap1\pardeftab720\qr\partightenfactor0
\cf0 44128\cell
\pard\intbl\itap1\pardeftab720\qr\partightenfactor0
\cf0 25.17\cell
\pard\intbl\itap1\pardeftab720\qr\partightenfactor0
\cf0 67.63\cell \row
\itap1\trowd \taflags1 \trgaph108\trleft-108 \trbrdrl\brdrnil \trbrdrr\brdrnil
\clvertalc \clshdrawnil \clbrdrt\brdrs\brdrw20\brdrcf2 \clbrdrl\brdrs\brdrw20\brdrcf2 \clbrdrb\brdrs\brdrw20\brdrcf2 \clbrdrr\brdrs\brdrw20\brdrcf2 \clpadl100 \clpadr100 \gaph\cellx2160
\clvertalc \clshdrawnil \clbrdrt\brdrs\brdrw20\brdrcf2 \clbrdrl\brdrs\brdrw20\brdrcf2 \clbrdrb\brdrs\brdrw20\brdrcf2 \clbrdrr\brdrs\brdrw20\brdrcf2 \clpadl100 \clpadr100 \gaph\cellx4320
\clvertalc \clshdrawnil \clbrdrt\brdrs\brdrw20\brdrcf2 \clbrdrl\brdrs\brdrw20\brdrcf2 \clbrdrb\brdrs\brdrw20\brdrcf2 \clbrdrr\brdrs\brdrw20\brdrcf2 \clpadl100 \clpadr100 \gaph\cellx6480
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

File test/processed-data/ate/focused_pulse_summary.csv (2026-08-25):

timestamp | test_name | repeat | dio | load_resistance_ohm | pulse_requested_ms | pulse_actual_ms | aborted | lost_samples | corrupted_samples | baseline_vbat_V | vbat_min_V | battery_droop_mV | time_min_after_load_on_ms | avg_added_current_mA | max_added_current_mA | avg_total_current_mA | max_total_current_mA | vpcb_min_V | immediate_recovery_vbat_V | waveform_file
2026-08-21T12:09:03 | 550ohm_10ms | 1 | 1 | 550.4 | 10.0 | 40.26366607286036 | False | 0 | 0 | 3.0461918449330345 | 2.9599342693570425 | 86.257575575992 | 9.74637500993908 | 7.017420074847337 | 7.918995395182378 | 6.860914403859338 | 7.7624897241943795 | 2.9558201498032193 | 3.0453276946661956 | results/focused_pulse/waveforms/550ohm_10ms_repeat1.csv
2026-08-21T12:10:09 | 550ohm_10ms | 2 | 1 | 550.4 | 10.0 | 9.225042071193457 | False | 0 | 0 | 3.0450406210182286 | 2.9526109620109464 | 92.42965900728217 | 4.262832987569299 | 6.6654629429591745 | 7.674431030911971 | 6.753521636241585 | 7.7624897241943795 | 2.948496842457123 | 3.045367972856599 | results/focused_pulse/waveforms/550ohm_10ms_repeat2.csv
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

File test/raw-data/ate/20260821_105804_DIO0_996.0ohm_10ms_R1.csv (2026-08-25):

time_s | ch1_raw_V | vbat_V
0.0 | -0.0017542171334394784 | 3.022182381798859
1e-05 | -0.0020934453801375046 | 3.018520728125811
2e-05 | -0.0020934453801375046 | 3.022182381798859
3e-05 | -0.0020934453801375046 | 3.022182381798859
4e-05 | -0.0020934453801375046 | 3.022182381798859
5e-05 | -0.0020934453801375046 | 3.022182381798859
6e-05 | -0.0020934453801375046 | 3.022182381798859
7e-05 | -0.0020934453801375046 | 3.022182381798859
8e-05 | -0.0020934453801375046 | 3.025844035471907
9e-05 | -0.0020934453801375046 | 3.018520728125811
0.0001 | -0.0020934453801375046 | 3.025844035471907
0.00011 | -0.0017542171334394784 | 3.022182381798859
0.00012 | -0.0020934453801375046 | 3.022182381798859
0.00013 | -0.0017542171334394784 | 3.022182381798859
0.00014 | -0.0020934453801375046 | 3.022182381798859
0.00015 | -0.0017542171334394784 | 3.022182381798859
0.00016 | -0.0020934453801375046 | 3.022182381798859
0.00017 | -0.0017542171334394784 | 3.022182381798859
0.00018 | -0.0020934453801375046 | 3.022182381798859
0.00019 | -0.0020934453801375046 | 3.018520728125811
0.0002 | -0.0020934453801375046 | 3.018520728125811
0.00021 | -0.0017542171334394784 | 3.022182381798859
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

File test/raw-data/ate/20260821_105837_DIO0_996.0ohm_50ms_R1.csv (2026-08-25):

time_s | ch1_raw_V | vbat_V
0.0 | -0.0007365323933453994 | 3.033167342818003
1e-05 | -0.0007365323933453994 | 3.036828996491051
2e-05 | -0.0010757606400434256 | 3.036828996491051
3e-05 | -0.0007365323933453994 | 3.036828996491051
4e-05 | -0.0010757606400434256 | 3.036828996491051
5e-05 | -0.0007365323933453994 | 3.036828996491051
6e-05 | -0.0007365323933453994 | 3.036828996491051
7e-05 | -0.0007365323933453994 | 3.036828996491051
8e-05 | -0.0007365323933453994 | 3.036828996491051
9e-05 | -0.0007365323933453994 | 3.036828996491051
0.0001 | -0.0007365323933453994 | 3.036828996491051
0.00011 | -0.0007365323933453994 | 3.036828996491051
0.00012 | -0.0007365323933453994 | 3.036828996491051
0.00013 | -0.0010757606400434256 | 3.036828996491051
0.00014 | -0.0007365323933453994 | 3.036828996491051
0.00015 | -0.0007365323933453994 | 3.036828996491051
0.00016 | -0.0007365323933453994 | 3.036828996491051
0.00017 | -0.0007365323933453994 | 3.036828996491051
0.00018 | -0.0007365323933453994 | 3.036828996491051
0.00019 | -0.0007365323933453994 | 3.036828996491051
0.0002 | -0.0007365323933453994 | 3.033167342818003
0.00021 | -0.0007365323933453994 | 3.036828996491051
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

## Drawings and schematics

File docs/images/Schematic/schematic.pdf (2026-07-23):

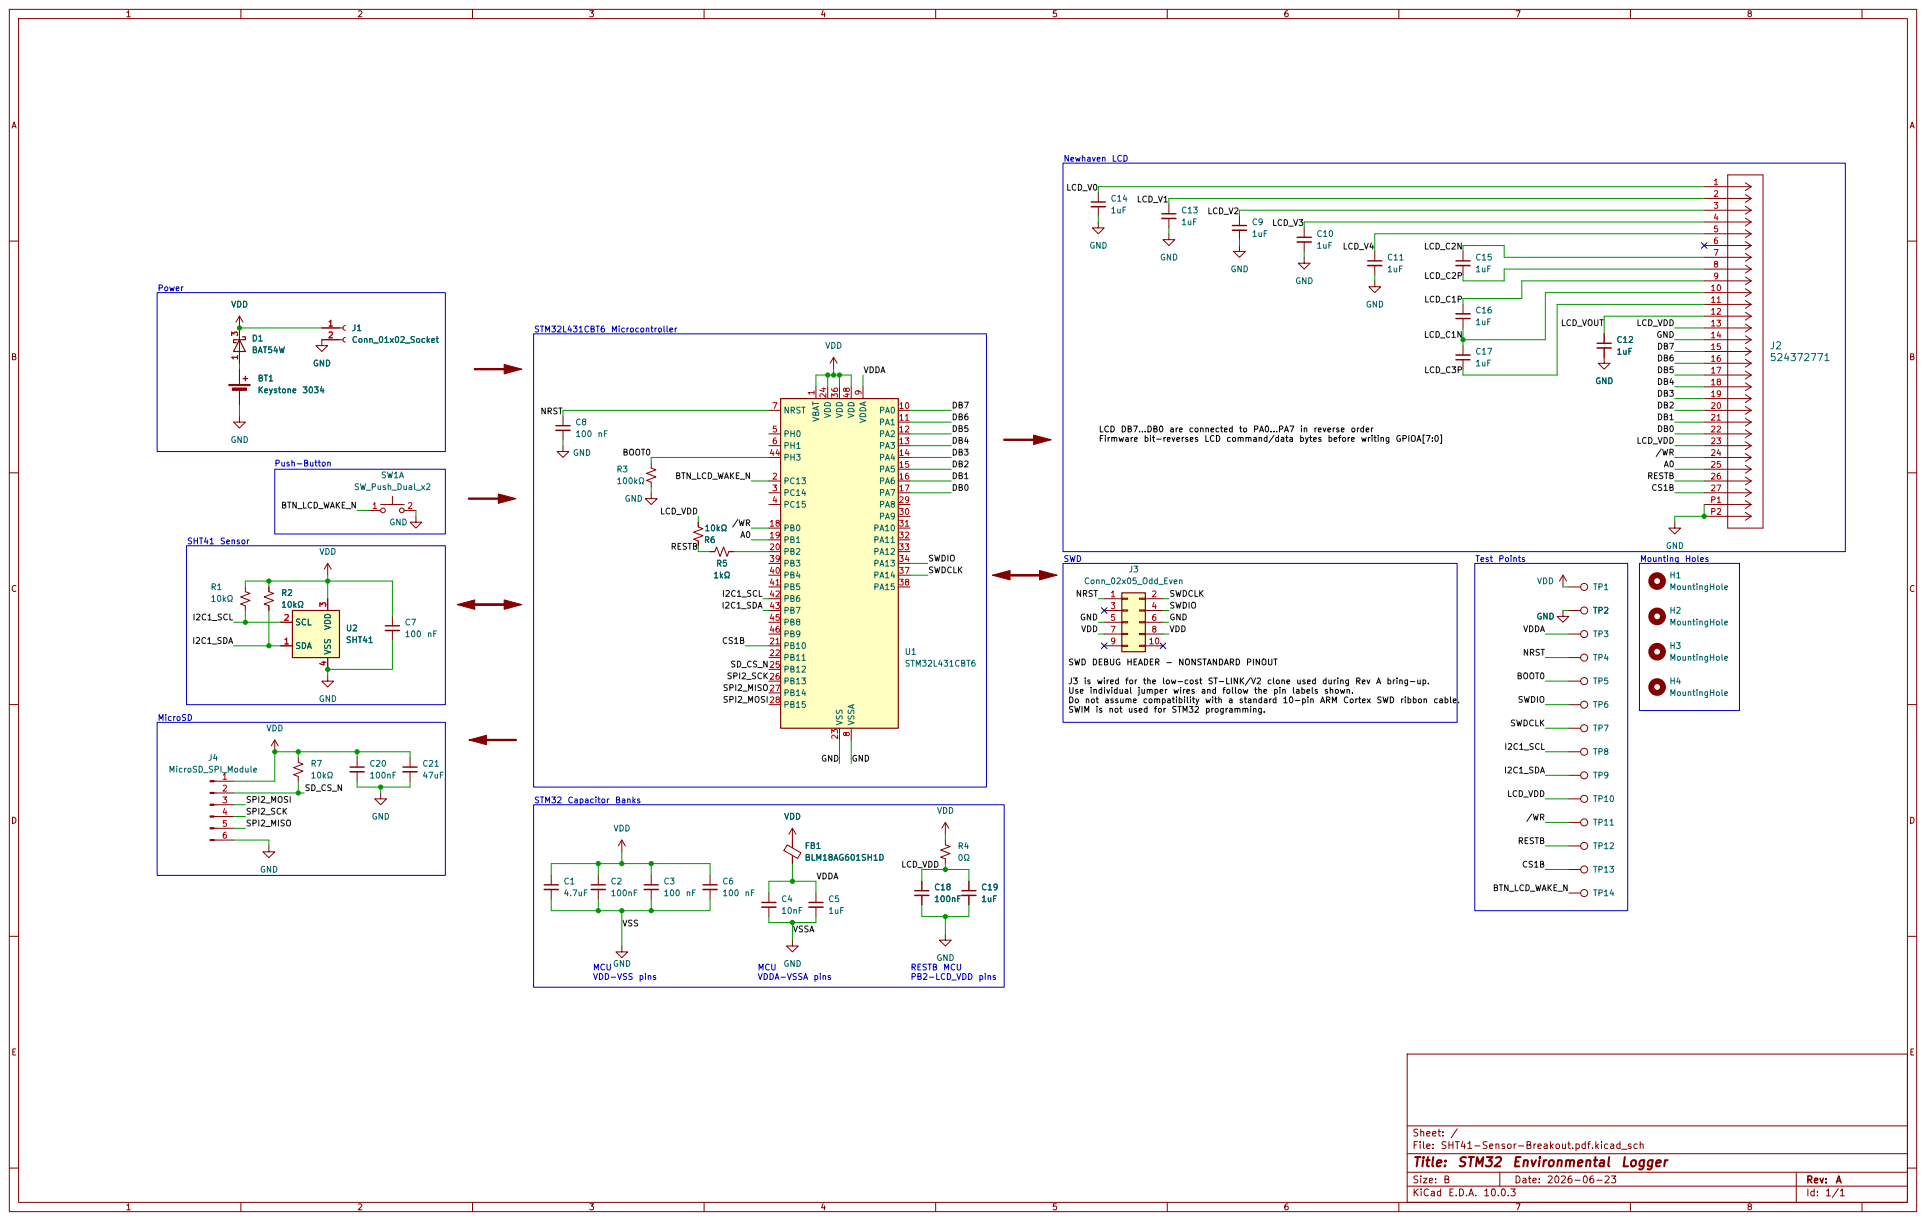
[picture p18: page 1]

LCD DB7...DB0 are connected to PA0...PA7 in reverse order Firmware bit-reverses LCD command/data bytes before writing GPIOA[7:0] MCU

J3 is wired for the low-cost ST-LINK/V2 clone used during Rev A bring-up. Use individual jumper wires and follow the pin labels shown. Do not assume compatibility with a standard 10-pin ARM Cortex SWD ribbon cable. SWIM is not used for STM32 programming. R2

Sheet: /
File: SHT41-Sensor-Breakout.pdf.kicad_sch
Title: STM32 Environmental Logger

Size: B | Rev: A
KiCad E.D.A. 10.0.3 | Id: 1/1

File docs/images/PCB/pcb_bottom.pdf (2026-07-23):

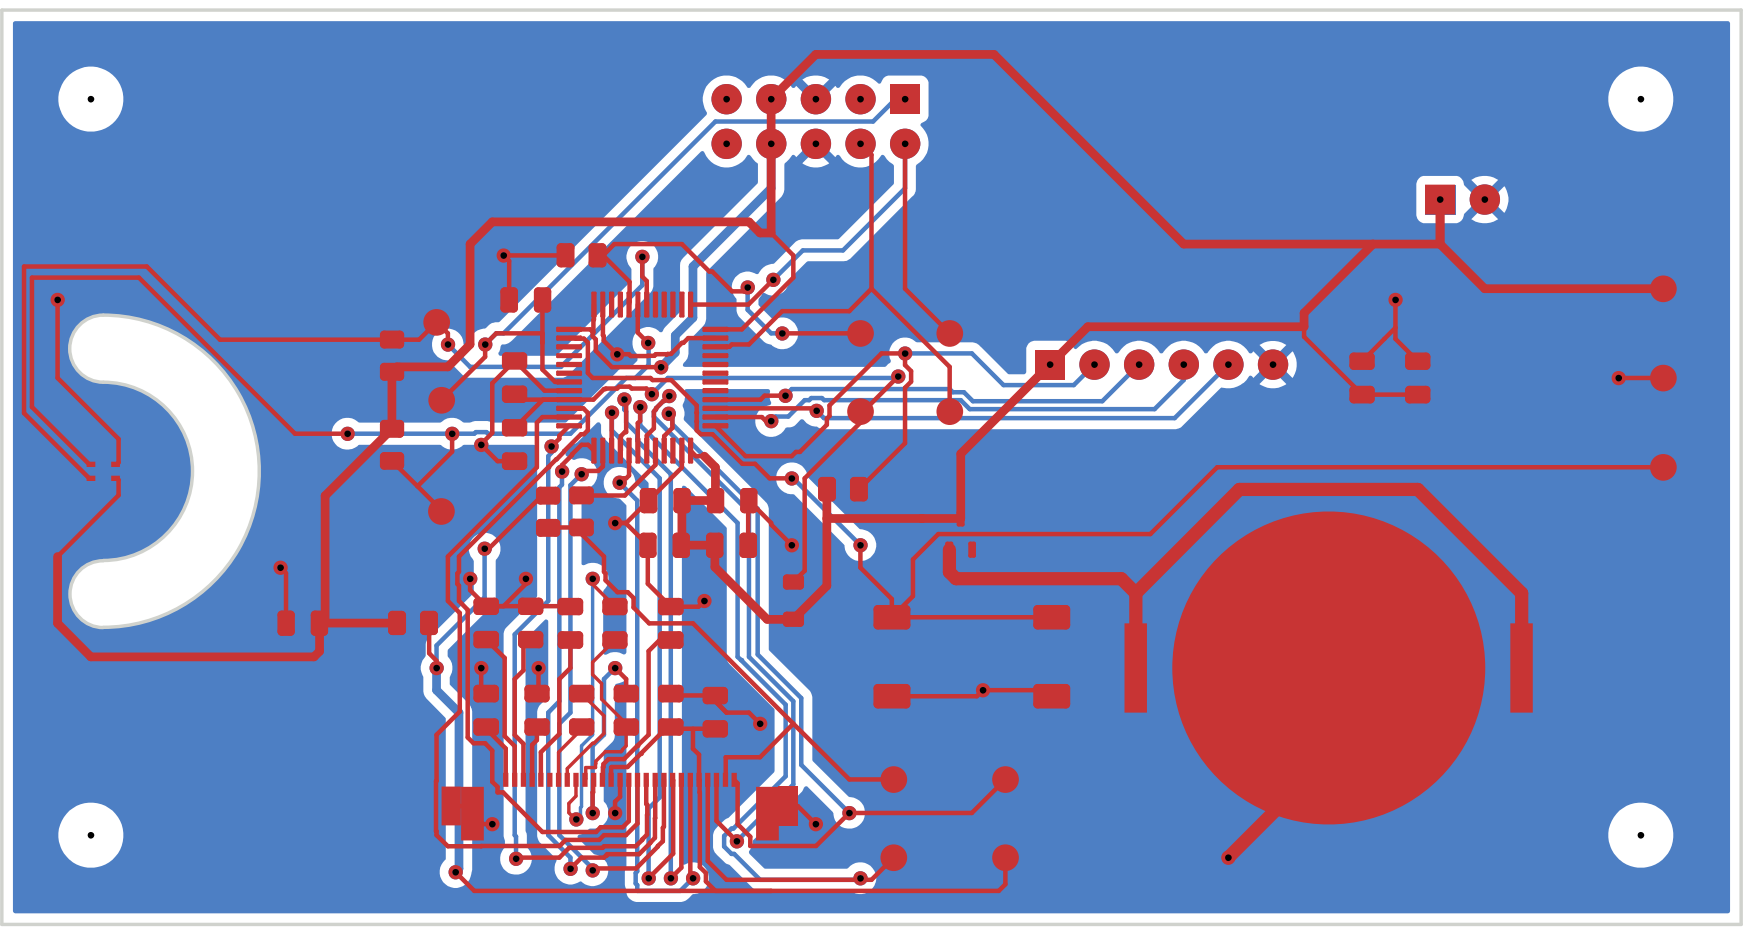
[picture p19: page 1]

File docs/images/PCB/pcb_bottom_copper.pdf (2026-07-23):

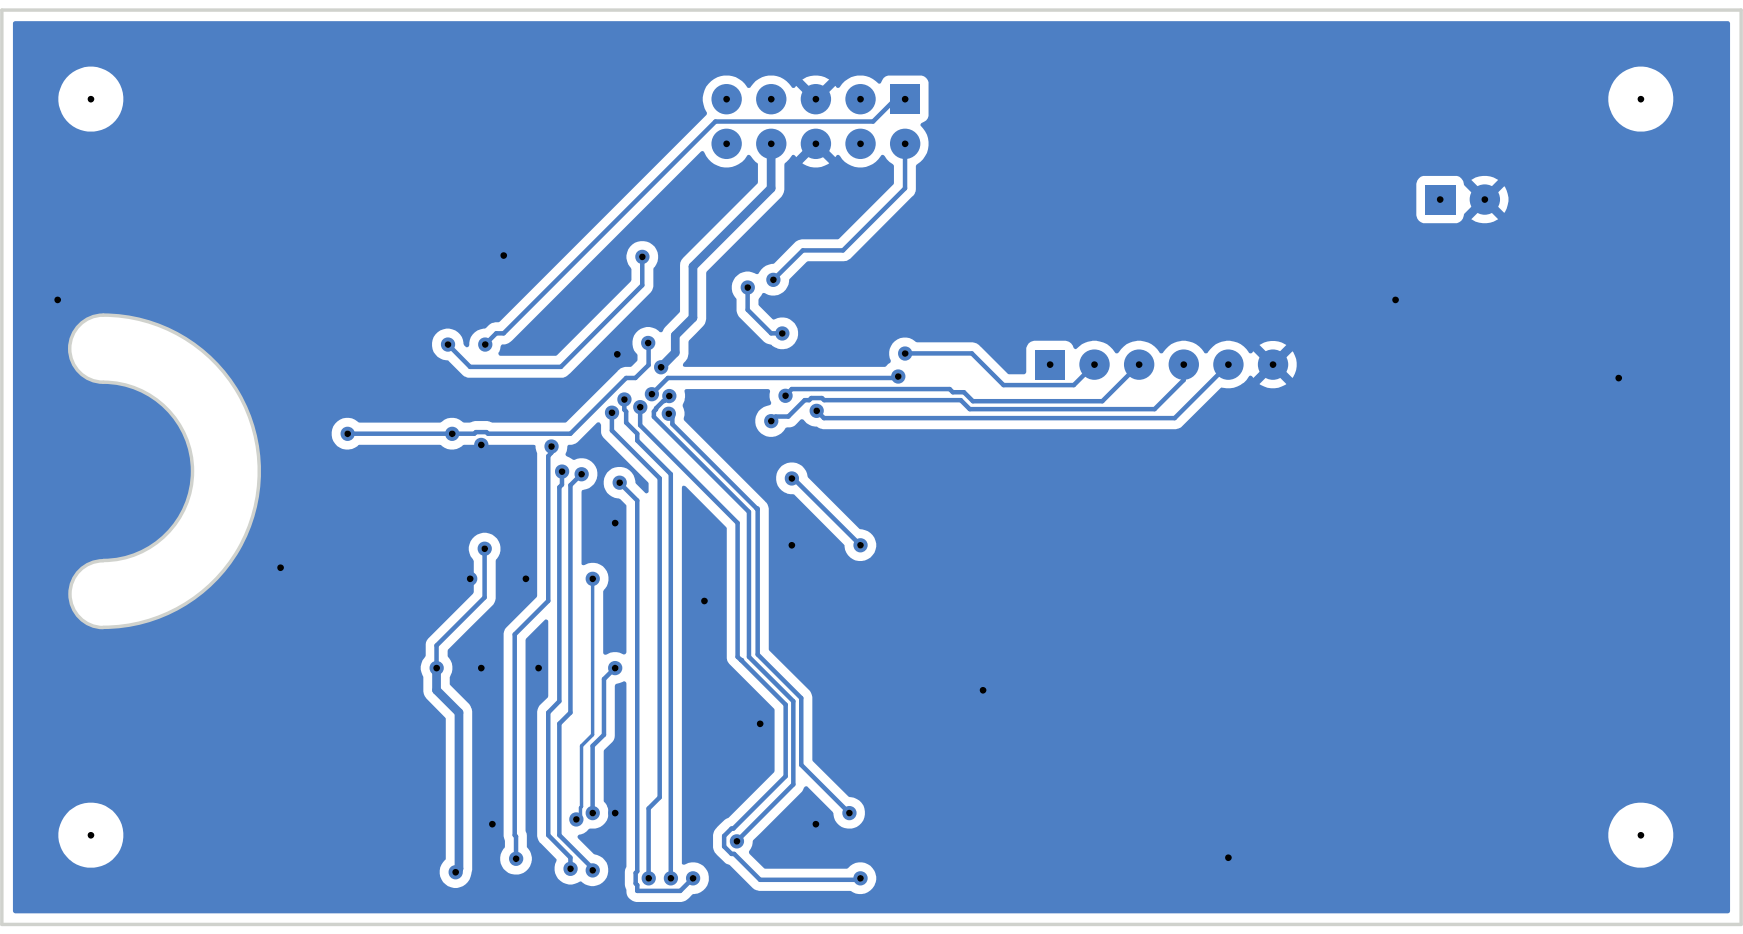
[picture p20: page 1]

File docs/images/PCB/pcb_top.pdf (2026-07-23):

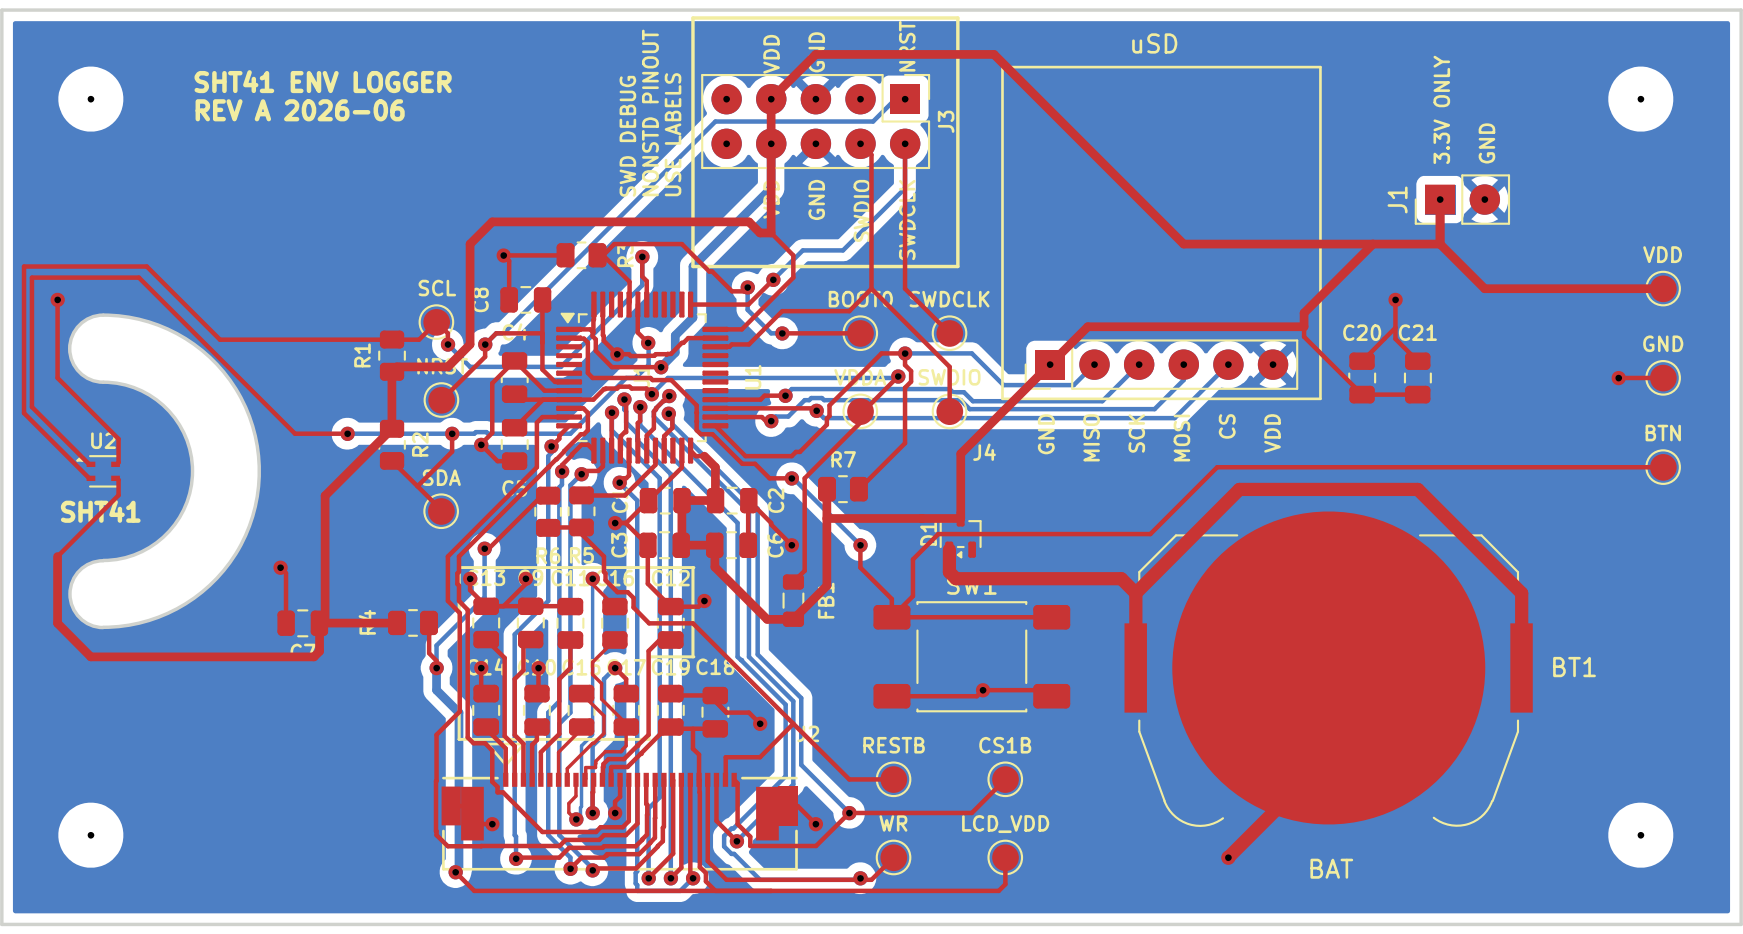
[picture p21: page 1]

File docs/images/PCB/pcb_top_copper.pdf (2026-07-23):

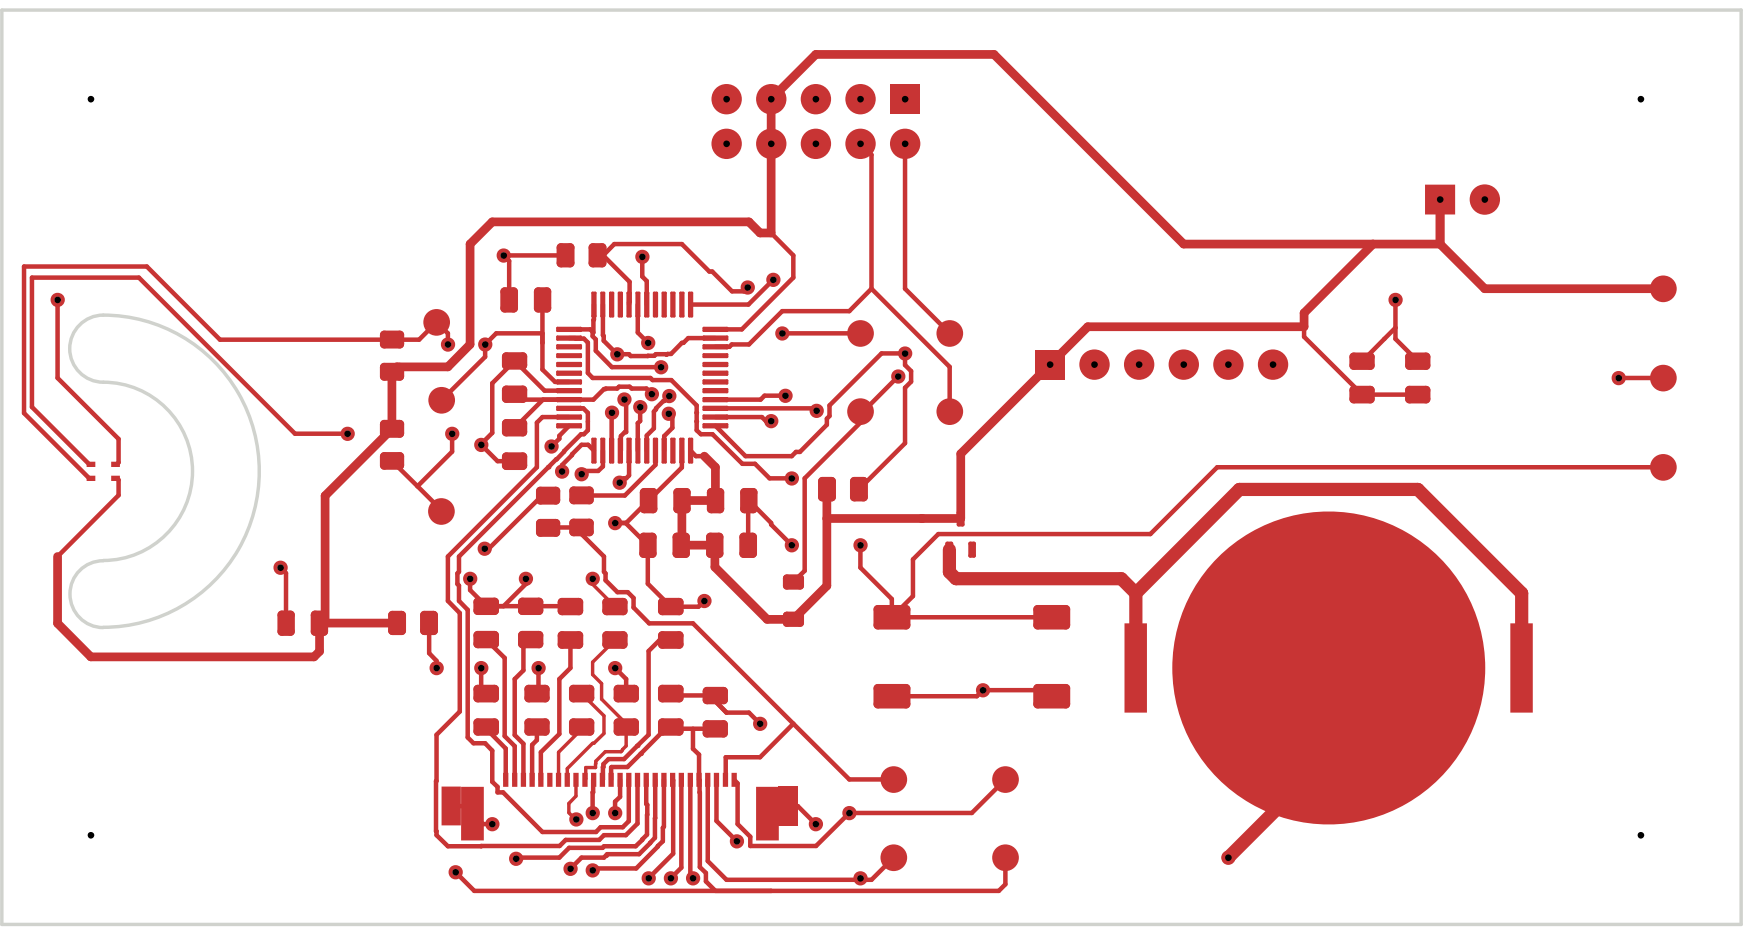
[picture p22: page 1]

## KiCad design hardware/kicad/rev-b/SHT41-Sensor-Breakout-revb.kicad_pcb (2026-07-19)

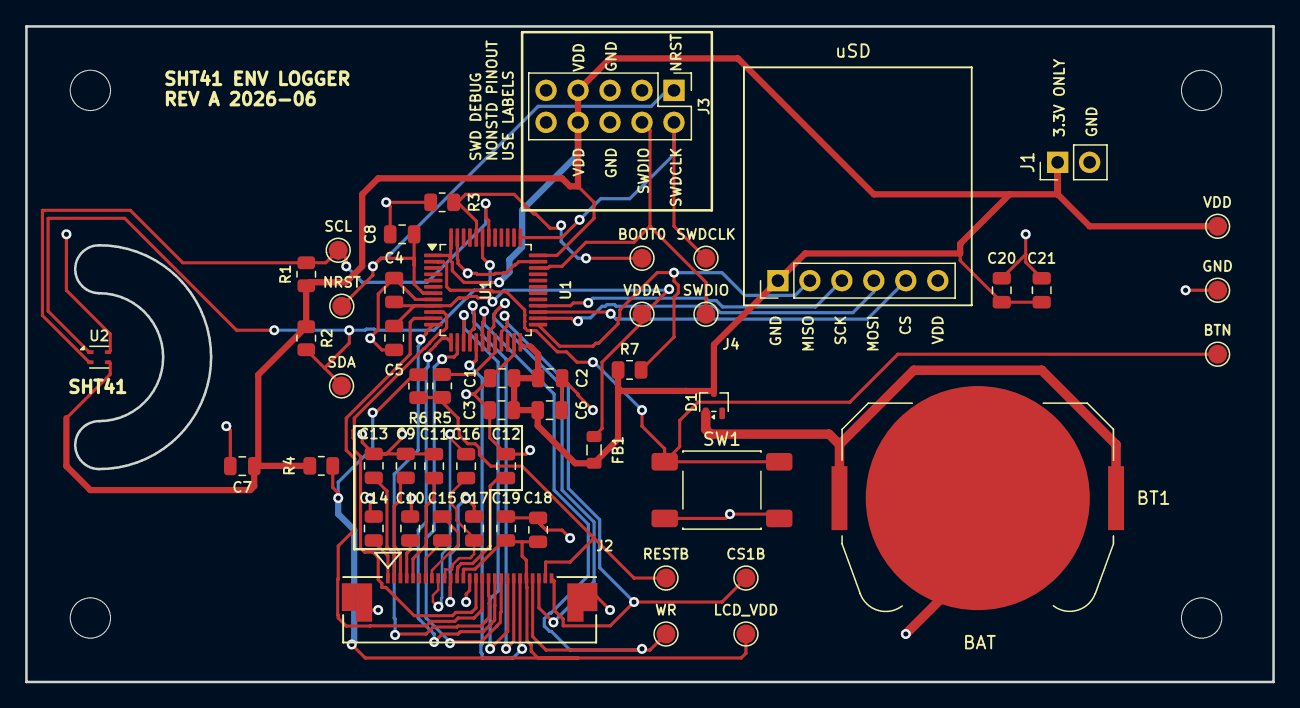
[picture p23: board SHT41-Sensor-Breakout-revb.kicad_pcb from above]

Board: 2 copper layers, 99.1 x 52.1 mm, 56 parts (0 on the bottom side), 40 nets.

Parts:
BT1: Keystone 3034; BatteryHolder_Keystone_3034_1x20mm
C1: 4.7uF; C_0805_2012Metric
C2, C18, C20: 100nF; C_0805_2012Metric
C3, C6, C7, C8: 100 nF; C_0805_2012Metric
C4: 10nF; C_0805_2012Metric
C5, C9, C10, C11, C12, C13, C14, C15, C16, C17, C19: 1uF; C_0805_2012Metric
C21: 47uF; C_0805_2012Metric
D1: BAT54W; SOT-323_SC-70
FB1: BLM18AG601SH1D; L_0805_2012Metric
H1, H2, H3, H4: MountingHole; MountingHole_3.2mm_M3
J1: Conn_01x02_Socket; PinHeader_1x02_P2.54mm_Vertical
J2: 524372771; Molex_52437-2771_Custom
J3: Conn_02x05_Odd_Even; PinHeader_2x05_P2.54mm_Vertical
J4: MicroSD_SPI_Module; PinHeader_1x06_P2.54mm_Vertical
R1, R2, R6, R7: 10kΩ; R_0805_2012Metric
R3: 100kΩ; R_0805_2012Metric
R4: 0Ω; R_0805_2012Metric
R5: 1kΩ; R_0805_2012Metric
SW1: SW_Push_Dual_x2; SW_Push_1P1T_NO_E-Switch_TL3301NxxxxxG
TP1: VDD; TestPoint_Pad_D1.5mm
TP2: GND; TestPoint_Pad_D1.5mm
TP3: VDDA; TestPoint_Pad_D1.5mm
TP4: NRST; TestPoint_Pad_D1.5mm
TP5: BOOT0; TestPoint_Pad_D1.5mm
TP6: SWDIO; TestPoint_Pad_D1.5mm
TP7: SWDCLK; TestPoint_Pad_D1.5mm
TP8: SCL; TestPoint_Pad_D1.5mm
TP9: SDA; TestPoint_Pad_D1.5mm
TP10: LCD_VDD; TestPoint_Pad_D1.5mm
TP11: WR; TestPoint_Pad_D1.5mm
TP12: RESTB; TestPoint_Pad_D1.5mm
TP13: CS1B; TestPoint_Pad_D1.5mm
TP14: BTN; TestPoint_Pad_D1.5mm
U1: STM32L431CBT6; LQFP-48_7x7mm_P0.5mm
U2: SHT41; Sensirion_DFN-4_1.5x1.5mm_P0.8mm_SHT4x_NoCentralPad

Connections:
/A0: J2.25, U1.19 (PB1)
/BOOT0: R3.1, TP5.1 (1_1), U1.44 (PH3)
/BTN_LCD_WAKE_N: SW1.1 (C), TP14.1 (1_1), U1.2 (PC13)
/CS1B: J2.27, TP13.1 (1_1), U1.21 (PB10)
/DB0: J2.22, U1.17 (PA7)
/DB1: J2.21, U1.16 (PA6)
/DB2: J2.20, U1.15 (PA5)
/DB3: J2.19, U1.14 (PA4)
/DB4: J2.18, U1.13 (PA3)
/DB5: J2.17, U1.12 (PA2)
/DB6: J2.16, U1.11 (PA1)
/DB7: J2.15, U1.10 (PA0)
/I2C1_SCL: R1.2, TP8.1 (1_1), U1.42 (PB6), U2.2 (SCL)
/I2C1_SDA: R2.2, TP9.1 (1_1), U1.43 (PB7), U2.1 (SDA)
/LCD_C1N: C16.1, C17.2, J2.10
/LCD_C1P: C16.2, J2.9
/LCD_C2N: C15.1, J2.7
/LCD_C2P: C15.2, J2.8
/LCD_C3P: C17.1, J2.11
/LCD_V0: C14.1, J2.1
/LCD_V1: C13.1, J2.2
/LCD_V2: C9.1, J2.3
/LCD_V3: C10.1, J2.4
/LCD_V4: C11.1, J2.5
/LCD_VDD: C18.1, C19.1, J2.13, J2.23, R4.2, R6.2, TP10.1 (1_1)
/LCD_VOUT: C12.1, J2.12
/NRST: C8.1, J3.1, TP4.1 (1_1), U1.7 (NRST)
/RESTB: J2.26, R5.2, R6.1, TP12.1 (1_1)
/SD_CS_N: J4.2, R7.2, U1.25 (PB12)
/SPI2_MISO: J4.5, U1.27 (PB14)
/SPI2_MOSI: J4.3, U1.28 (PB15)
/SPI2_SCK: J4.4, U1.26 (PB13)
/SWDCLK: J3.2, TP7.1 (1_1), U1.37 (PA14)
/SWDIO: J3.4, TP6.1 (1_1), U1.34 (PA13)
/VDDA: C4.1, C5.1, FB1.2, TP3.1 (1_1), U1.9 (VDDA)
//WR: J2.24, TP11.1 (1_1), U1.18 (PB0)
GND: BT1.2 (-), C1.2, C2.2, C3.2, C4.2, C5.2, C6.2, C7.2, C8.2, C9.2, C10.2, C11.2, C12.2, C13.2, C14.2, C18.2, C19.2, C20.2, C21.2, J1.2, J2.14, J2.P1, J2.P2, J3.5, J3.6, J4.6, R3.2, SW1.2 (D), TP2.1 (1_1), U1.8 (VSSA), U1.23 (VSS), U1.35 (VSS), U1.47 (VSS), U2.4 (VSS)
unnamed: BT1.1 (+), D1.1 (A)
unnamed: R5.1, U1.20 (PB2)
VDD: C1.1, C2.1, C3.1, C6.1, C7.1, C20.1, C21.1, D1.3 (K), FB1.1, J1.1, J3.7, J3.8, J4.1, R1.1, R2.1, R4.1, R7.1, TP1.1 (1_1), U1.1 (VBAT), U1.24 (VDD), U1.36 (VDD), U1.48 (VDD), U2.3 (VDD)

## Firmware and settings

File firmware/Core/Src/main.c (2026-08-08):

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
/* Includes ------------------------------------------------------------------*/
#include "main.h"
#include "fatfs.h"

/* USER CODE BEGIN Includes */

#include <string.h>
#include <stdio.h>
#include <stdlib.h>

/* USER CODE END Includes */

/* USER CODE BEGIN PD */

#define RTC_BKP_MAGIC 0x32F2U
#define LOG_INTERVAL_MS 5000U
#define BUTTON_DEBOUNCE_MS 30U

/* USER CODE END PD */

I2C_HandleTypeDef hi2c1;

RTC_HandleTypeDef hrtc;

SPI_HandleTypeDef hspi2;

/* USER CODE BEGIN PV */

volatile FRESULT mount_res = 99;
volatile FRESULT open_res  = 99;
volatile FRESULT write_res = 99;
volatile FRESULT sync_res  = 99;
volatile FRESULT close_res = 99;
volatile uint8_t logging_enabled = 0;
volatile GPIO_PinState button_state_dbg = GPIO_PIN_SET;
volatile uint32_t button_press_count = 0;

uint32_t last_sample_ms = 0;

volatile HAL_StatusTypeDef sht_res = HAL_ERROR;
volatile int temp_x100_dbg = 0;
volatile int rh_x100_dbg = 0;
volatile uint32_t sample_count = 0;

UINT bytes_written = 0;
FIL file;

GPIO_PinState button_raw = GPIO_PIN_SET;
GPIO_PinState button_stable = GPIO_PIN_SET;
GPIO_PinState button_last_raw = GPIO_PIN_SET;

uint32_t button_change_ms = 0;

/* USER CODE END PV */

void SystemClock_Config(void);
static void MX_GPIO_Init(void);
static void MX_SPI2_Init(void);
static void MX_I2C1_Init(void);
static void MX_RTC_Init(void);
/* USER CODE BEGIN PFP */

static HAL_StatusTypeDef SHT41_Read(float *temp_c, float *rh_pct);
static void LogSampleToSD(void);

/* USER CODE END PFP */

/* USER CODE BEGIN 0 */

#define SHT41_ADDR (0x44 << 1)

static HAL_StatusTypeDef SHT41_Read(float *temp_c, float *rh_pct)
{
    uint8_t cmd = 0xFD;
    uint8_t rx[6];

    HAL_StatusTypeDef ret;

    ret = HAL_I2C_Master_Transmit(&hi2c1, SHT41_ADDR, &cmd, 1, 100);
    if (ret != HAL_OK) return ret;

    HAL_Delay(10);

    ret = HAL_I2C_Master_Receive(&hi2c1, SHT41_ADDR, rx, 6, 100);
    if (ret != HAL_OK) return ret;

    uint16_t raw_t  = ((uint16_t)rx[0] << 8) | rx[1];
    uint16_t raw_rh = ((uint16_t)rx[3] << 8) | rx[4];

    *temp_c = -45.0f + 175.0f * ((float)raw_t / 65535.0f);
    *rh_pct = -6.0f + 125.0f * ((float)raw_rh / 65535.0f);

    if (*rh_pct < 0.0f) *rh_pct = 0.0f;
    if (*rh_pct > 100.0f) *rh_pct = 100.0f;

    return HAL_OK;
}

static void LogSampleToSD(void)
{
    char line[96];
    RTC_TimeTypeDef rtc_time = {0};
    RTC_DateTypeDef rtc_date = {0};
    float temp_c = 0.0f;
    float rh_pct = 0.0f;

    sht_res = SHT41_Read(&temp_c, &rh_pct);

    if (sht_res != HAL_OK)
    {
        temp_c = -99.99f;
        rh_pct = 0.0f;
    }

    int temp_x100 = (int)(temp_c * 100.0f);
    int rh_x100   = (int)(rh_pct * 100.0f);

    temp_x100_dbg = temp_x100;
    rh_x100_dbg = rh_x100;

    HAL_RTC_GetTime(&hrtc, &rtc_time, RTC_FORMAT_BIN);
    HAL_RTC_GetDate(&hrtc, &rtc_date, RTC_FORMAT_BIN);

    snprintf(line, sizeof(line),
             "%lu,20%02u-%02u-%02u %02u:%02u:%02u,%d.%02d,%d.%02d\r\n",
             (unsigned long)sample_count++,
             rtc_date.Year, rtc_date.Month, rtc_date.Date,
             rtc_time.Hours, rtc_time.Minutes, rtc_time.Seconds,
             temp_x100 / 100, abs(temp_x100 % 100),
             rh_x100 / 100, abs(rh_x100 % 100));

    open_res = 99;
    write_res = 99;
    sync_res = 99;
    close_res = 99;
    bytes_written = 0;

    if (mount_res == FR_OK)
    {
        open_res = f_open(&file, "log.csv",
                          FA_OPEN_APPEND | FA_WRITE);

        if (open_res == FR_OK)
        {
            FRESULT header_res = FR_OK;
            UINT header_bytes = 0;

            if (f_size(&file) == 0)
            {
                const char *header =
                    "sample,timestamp,temp_C,rh_pct\r\n";

                header_res = f_write(&file,
                                     header,
                                     strlen(header),
                                     &header_bytes);
            }

            if (header_res == FR_OK)
            {
                write_res = f_write(&file,
                                    line,
                                    strlen(line),
                                    &bytes_written);

                if (write_res == FR_OK)
                {
                    sync_res = f_sync(&file);
                }
            }

            close_res = f_close(&file);
        }
    }
}

/* Keep SD/SPI command functions out of main.c.
   They belong in user_diskio.c for FatFs testing. */

/* USER CODE END 0 */

/**
  * @brief  The application entry point.
  * @retval int
  */
int main(void)
{

  /* MCU Configuration--------------------------------------------------------*/

  /* Reset of all peripherals, Initializes the Flash interface and the Systick. */
  HAL_Init();

  /* Configure the system clock */
  SystemClock_Config();

  /* Initialize all configured peripherals */
  MX_GPIO_Init();
  MX_SPI2_Init();
  MX_I2C1_Init();
  MX_FATFS_Init();
  MX_RTC_Init();
  /* USER CODE BEGIN 2 */

  mount_res = 99;
  open_res = 99;
  write_res = 99;
  sync_res = 99;
  close_res = 99;
  bytes_written = 0;

  f_mount(NULL, USERPath, 0);
  mount_res = f_mount(&USERFatFS, USERPath, 1);

  button_raw = HAL_GPIO_ReadPin(BTN_LCD_WAKE_N_GPIO_Port,
                               BTN_LCD_WAKE_N_Pin);

  button_stable = button_raw;
  button_last_raw = button_raw;
  button_change_ms = HAL_GetTick();

  /* Put breakpoint here */
  __NOP();

  /* USER CODE END 2 */

  /* Infinite loop */
  /* USER CODE BEGIN WHILE */
  while (1)
  {
    /* USER CODE END WHILE */

    /* USER CODE BEGIN 3 */

	  uint32_t now = HAL_GetTick();

	  button_raw = HAL_GPIO_ReadPin(BTN_LCD_WAKE_N_GPIO_Port,
	                               BTN_LCD_WAKE_N_Pin);

	  /* Restart debounce timer whenever the raw input changes */
	  if (button_raw != button_last_raw)
	  {
	      button_last_raw = button_raw;
	      button_change_ms = now;
	  }

	  /* Accept the state only after it remains stable */
	  if (((now - button_change_ms) >= BUTTON_DEBOUNCE_MS) &&
	      (button_raw != button_stable))
	  {
	      button_stable = button_raw;

	      /* Toggle only on the debounced press edge */
	      if (button_stable == GPIO_PIN_RESET)
	      {
	          logging_enabled ^= 1U;
	          button_press_count++;

	          if (logging_enabled)
	          {
	              LogSampleToSD();
	              last_sample_ms = now;
	          }
	      }
	  }

	  if (logging_enabled &&
	      ((now - last_sample_ms) >= LOG_INTERVAL_MS))
	  {
	      last_sample_ms = now;
	      LogSampleToSD();
	  }

	  HAL_Delay(1);

  /* USER CODE END 3 */
}
}

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


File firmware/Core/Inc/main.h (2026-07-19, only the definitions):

#define BTN_LCD_WAKE_N_Pin GPIO_PIN_13
#define BTN_LCD_WAKE_N_GPIO_Port GPIOC
#define LCD_DB7_Pin GPIO_PIN_0
#define LCD_DB7_GPIO_Port GPIOA
#define LCD_DB6_Pin GPIO_PIN_1
#define LCD_DB6_GPIO_Port GPIOA
#define LCD_DB5_Pin GPIO_PIN_2
#define LCD_DB5_GPIO_Port GPIOA
#define LCD_DB4_Pin GPIO_PIN_3
#define LCD_DB4_GPIO_Port GPIOA
#define LCD_DB3_Pin GPIO_PIN_4
#define LCD_DB3_GPIO_Port GPIOA
#define LCD_DB2_Pin GPIO_PIN_5
#define LCD_DB2_GPIO_Port GPIOA
#define LCD_DB1_Pin GPIO_PIN_6
#define LCD_DB1_GPIO_Port GPIOA
#define LCD_DB0_Pin GPIO_PIN_7
#define LCD_DB0_GPIO_Port GPIOA
#define LCD_WR_N_Pin GPIO_PIN_0
#define LCD_WR_N_GPIO_Port GPIOB
#define LCD_A0_Pin GPIO_PIN_1
#define LCD_A0_GPIO_Port GPIOB
#define LCD_RESET_N_Pin GPIO_PIN_2
#define LCD_RESET_N_GPIO_Port GPIOB
#define LCD_CS_N_Pin GPIO_PIN_10
#define LCD_CS_N_GPIO_Port GPIOB
#define SD_CS_N_Pin GPIO_PIN_12
#define SD_CS_N_GPIO_Port GPIOB
#define SD_SCK_Pin GPIO_PIN_13
#define SD_SCK_GPIO_Port GPIOB
#define SD_MISO_Pin GPIO_PIN_14
#define SD_MISO_GPIO_Port GPIOB
#define SD_MOSI_Pin GPIO_PIN_15
#define SD_MOSI_GPIO_Port GPIOB

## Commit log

2026-07-19 hardware: add KiCad design sources
    [2993.STEP, 3034.step, 524372771.stp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]
2026-07-19 firmware: add STM32L431 logger implementation
2026-07-19 build: add STM32CubeIDE project metadata
2026-07-23 docs: update schematic title block
    [SHT41-Sensor-Breakout.kicad_sch]
2026-07-23 build: add portable debug configuration
    [SHT41_Bringup Debug.cfg]
2026-07-23 docs: add PCB render images
2026-07-23 hardware: add PCB manufacturing outputs
    [SHT41-Sensor-Breakout-B_Cu.gbr, SHT41-Sensor-Breakout-B_Mask.gbr, SHT41-Sensor-Breakout-B_Paste.gbr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]
2026-07-23 test: add representative environmental log sample
    [environmental-log-sample.csv]
2026-08-08 sync: preserve Windows RTC logging and validation updates
    [environmental-shunt-waveform.csv]
2026-08-08 sync: preserve Mac CSV data updates
    [environmental-rcc_log_sample.csv, environmental-shunt-log-sample.csv]
2026-08-08 Update README.md
    Added push-button, current measurement, and related debugging/troubleshooting
2026-08-11 docs: archive KiCad source as Rev A hardware baseline
    [SHT41-Sensor-Breakout.kicad_pcb, SHT41-Sensor-Breakout.kicad_sch]
2026-08-25 design: add Rev B schematic and component libraries
    [CYBLE-416045-02.step, DBV0006A.stp, LFXTAL016178.step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]
2026-08-25 test: add automated CR2032 characterization framework
    [20260821_105804_DIO0_996.0ohm_10ms_R1.csv, 20260821_105837_DIO0_996.0ohm_50ms_R1.csv, 20260821_105910_DIO0_996.0ohm_100ms_R1.csv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]

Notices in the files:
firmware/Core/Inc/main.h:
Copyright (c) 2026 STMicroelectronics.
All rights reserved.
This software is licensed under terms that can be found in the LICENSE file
